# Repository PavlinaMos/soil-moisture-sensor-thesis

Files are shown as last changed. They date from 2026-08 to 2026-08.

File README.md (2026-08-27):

# Soil Moisture Sensor Thesis

This repository contains the soil-moisture measurement project:

- ESP32 firmware for impedance measurement, Wi-Fi provisioning, and Arduino Cloud publishing.
- KiCad schematic and PCB sources for the measurement hardware.
- R scripts used to analyze the soil samples examined in impedance spectroscopy 
- The editable LaTeX thesis and its figures.

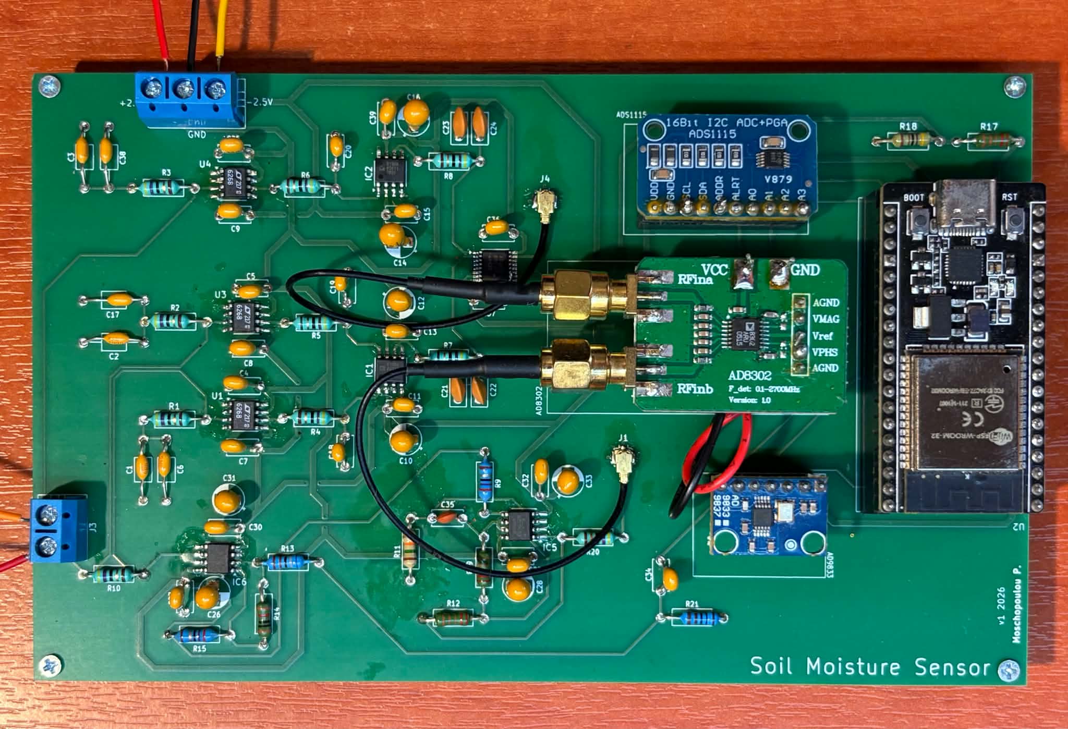
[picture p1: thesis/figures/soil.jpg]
Assembled soil moisture sensor


## Repository layout

```text
.
|-- firmware/                           ESP32 PlatformIO project
|   |-- include/                        Cloud definitions and local secrets
|   |-- src/                            Application code
|   `-- platformio.ini                  Board, framework, and library settings        
|-- analysis/impedance_spectroscopy/    R analysis scripts and usage notes
|-- PCB/kicad/soil-board/               KiCad schematic, PCB, and project files
|-- thesis/                             LaTeX sources, bibliography, and figures
```

## Firmware overview

The firmware targets an ESP32 NodeMCU-32S. It drives the measurement circuit,
calculates resistance (`RP`) and capacitance (`CP`), and publishes the results
to Arduino Cloud.

WiFiManager handles Wi-Fi setup without needing hard-coded network credentials. Known
networks are stored in the ESP32's non-volatile memory. At startup, the device
tries to connect to saved networks and opens a setup portal when none can
be reached.

### Analog parts

1. LTC6268
2. AD8130
3. AD8066
4. ADG733

### Modules

1. AD9833 waveform generator
2. ADS1115 ADC
3. AD8302 gain-phase detector

## Firmware development environment

Install:

1. [Visual Studio Code](https://code.visualstudio.com/)
2. The PlatformIO IDE extension for VS Code
3. The CP210x USB-to-UART driver if the ESP32 does not appear as a Windows COM port

Open the `firmware/` folder in VS Code. PlatformIO reads the exact toolchain and
library versions pinned in `firmware/platformio.ini`.

## Configure private secrets

Copy `firmware/include/arduino_secrets.h`, then add the matching Arduino Cloud
device key. Don't share its contents.

```cpp
#pragma once

#define SECRET_SSID ""
#define SECRET_PASS ""
#define SECRET_DEVICE_KEY "paste-your-Arduino-Cloud-device-key-here"
```

WiFiManager does not use `SECRET_SSID` or `SECRET_PASS` during normal
operation, they remain for compatibility. `SECRET_DEVICE_KEY` is required for
Arduino Cloud authentication.

## Build and upload the firmware

In VS Code, use the PlatformIO buttons in the bottom status bar:

- **Check mark**: build the project.
- **Right arrow**: upload the firmware to the ESP32.
- **Plug icon**: open the serial monitor.

The first build downloads and compiles dependencies, so it takes longer. 

To upload:

1. Connect the NodeMCU-32S using a USB data cable.
2. Confirm that Windows assigns it a COM port.
3. Click the PlatformIO **Upload** arrow.
4. If the board does not enter download mode automatically, hold **BOOT** until writing starts.

The serial monitor uses **115200 baud** and displays measurements, Wi-Fi state,
and Arduino Cloud connection messages.

## Wi-Fi provisioning

When no saved network can connect, the ESP32 creates the protected setup access
point `ESP32-Meter-Setup`. Connect with password `configure-me` and use the
captive portal (or `192.168.4.1`) to select a 2.4 GHz Wi-Fi network. The current
implementation stores up to five profiles; when the list is full, slot 0 is
replaced.

## Arduino Cloud

After joining Wi-Fi, the ESP32 connects to Arduino Cloud and publishes the
measurements periodically. The dashboard shows current `RP` and `CP` values and
their time history. Cloud retention depends on the Arduino Cloud plan.

## Hardware design

Open `PCB/kicad/soil-board/SoilBoard.kicad_pro` in KiCad. See the
[PCB notes](PCB/kicad/soil-board/README.md) for more info.

## Data analysis

The R scripts are under `analysis/impedance_spectroscopy/`. They cover
mean-squared error, Nyquist plots, sampled Nyquist comparisons, and
phase/impedance plots.

## Thesis

The thesis source is under `thesis/`. Its main document is `thesis/main.tex`
and it uses pdfLaTeX.

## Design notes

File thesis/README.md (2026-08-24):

#  Thesis - LaTeX project

This folder contains the current written progress of the thesis project.

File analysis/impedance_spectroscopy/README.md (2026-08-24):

# Impedance spectroscopy analysis

These scripts were used to process impedance measurements and create plots for
the thesis:

- `MeanSquaredError.R`: compares measured and modeled impedance and phase.
- `NyquistPlot.R`: plots Nyquist traces from CSV exports.
- `NyquistSamples.R`: compares selected trace groups 
- `PhaseVsFrequency.R`: plots impedance magnitude and phase against frequency.

The scripts are preserved as thesis analysis sources; they are not executed by
the ESP32 firmware build.

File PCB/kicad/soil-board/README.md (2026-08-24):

# SoilBoard KiCad project

Open `SoilBoard.kicad_pro` in KiCad to access the schematic and PCB layout.

## Included files

- `SoilBoard.kicad_pro`: KiCad project settings.
- `SoilBoard.kicad_sch`: schematic.
- `SoilBoard.kicad_pcb`: PCB layout.

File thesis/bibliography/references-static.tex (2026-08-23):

\begin{thebibliography}{99}
\addcontentsline{toc}{chapter}{ΒΙΒΛΙΟΓΡΑΦΙΑ}
\setlength{\itemsep}{0.45\baselineskip}\sloppy

\bibitem{ref01}
Soil Survey Staff, \emph{Soil Taxonomy: A Basic System of Soil
Classification for Making and Interpreting Soil Surveys}, 2nd ed., USDA
Handbook 436, Natural Resources Conservation Service, 1999.
\href{https://www.nrcs.usda.gov/resources/guides-and-instructions/soil-taxonomy}{Official
NRCS source}.

\bibitem{ref02}
Soil Science Division Staff, \emph{Soil Survey Manual}, C.
Ditzler, K. Scheffe, and H. C. Monger, eds., USDA Handbook 18, U.S.
Government Printing Office, 2017.
\href{https://www.nrcs.usda.gov/resources/guides-and-instructions/soil-survey-manual}{Official
NRCS source}.

\bibitem{ref03}
M. J. Escorihuela, P. de Rosnay, Y. H. Kerr, and J.-C. Calvet,
``Influence of Bound-Water Relaxation Frequency on Soil Moisture
Measurements,'' \emph{IEEE Transactions on Geoscience and Remote
Sensing}, vol. 45, no. 12, pp. 4067--4076, 2007.
\href{https://doi.org/10.1109/TGRS.2007.906090}{doi:10.1109/TGRS.2007.906090}.

\bibitem{ref04}
Keysight Technologies, \emph{Materials Testing: Electronic
Properties of Soil}, Application Note 5991-4717.

\bibitem{ref05}
METER Group, ``What Is Soil Moisture? The Science Behind the
Measurement.''
\href{https://metergroup.com/measurement-insights/what-is-soil-moisture-the-science-behind-the-measurement/}{Official
article}.

\bibitem{ref06}
Stevens Water Monitoring Systems, \emph{HydraProbe Soil Sensor
Documentation}.

\bibitem{ref07}
D. Neina, ``The Role of Soil pH in Plant Nutrition and Soil
Remediation,'' \emph{Applied and Environmental Soil Science}, vol. 2019,
Art. 5794869, 2019.
\href{https://doi.org/10.1155/2019/5794869}{doi:10.1155/2019/5794869}.

\bibitem{ref08}
University of Minnesota Extension, ``Soil Compaction.''
\href{https://extension.umn.edu/soil-management-and-health/soil-compaction}{Official
extension article}.

\bibitem{ref09}
J. D. Rhoades, F. Chanduvi, and S. M. Lesch, \emph{Soil Salinity
Assessment: Methods and Interpretation of Electrical Conductivity
Measurements}, FAO Irrigation and Drainage Paper 57, Food and
Agriculture Organization of the United Nations, 1999

\bibitem{ref10}
W. G. Fano, ``The Electrical Properties of Soils with Their
Applications to Agriculture, Geophysics, and Engineering,'' in
\emph{Electromagnetic Field Radiation in Matter}, IntechOpen, 2019.
\href{https://doi.org/10.5772/intechopen.88989}{doi:10.5772/intechopen.88989}.

\bibitem{ref11}
F. Wenner, ``A Method of Measuring Earth Resistivity,''
\emph{Bulletin of the Bureau of Standards}, vol. 12, pp. 469--478, 1916.
\href{https://nvlpubs.nist.gov/nistpubs/bulletin/12/nbsbulletinv12n4p469_A2b.pdf}{NIST
publication}.

\bibitem{ref12}
T. Barić, M. Pavić, and H. Glavaš, ``Modelling of the Wenner
Method Using the Finite Element Method,'' \emph{Engineering
Proceedings}, vol. 125, no. 1, Art. 10, 2026.
\href{https://doi.org/10.3390/engproc2026125010}{doi:10.3390/engproc2026125010}.

\bibitem{ref13}
J. D. Rhoades and R. D. Ingvalson, ``Determining Salinity in
Field Soils with Soil Resistance Measurements,'' \emph{Soil Science
Society of America Journal}, vol. 35, no. 1, pp. 54--60, 1971.
\href{https://doi.org/10.2136/sssaj1971.03615995003500010020x}{doi:10.2136/sssaj1971.03615995003500010020x}.

\bibitem{ref14}
N. Wiwattanachang, C. Vichalai, and P. H. Giao, ``Influence of
Calcium Carbonate Sludge on Cement-Stabilized Subgrade Quality as
Investigated by Means of Electrical Resistivity Measurements,''
\emph{Scientific Reports}, vol. 13, Art. 19392, 2023.
\href{https://doi.org/10.1038/s41598-023-46282-x}{doi:10.1038/s41598-023-46282-x}.

\bibitem{ref15}
S. Kaur, M. Sandhu, and J. Kaur, ``Dielectric Theory and Its
Properties,'' \emph{International Journal of Emerging Technologies in
Engineering Research (IJETER)}, vol. 4, no. 3, pp. 145--149, Mar. 2016.

\bibitem{ref16}
Electromagnetic Geophysics, ``Dielectric Permittivity.''
\href{https://em.geosci.xyz/content/physical_properties/dielectric_permittivity/index.html}{Official
reference page}.

\bibitem{ref17}
A. K. Bain and P. Chand, \emph{Pyroelectric Materials: Physics
and Applications}. Weinheim, Germany: Wiley-VCH, 2022

\bibitem{ref18}
Z. G. Datsios and P. N. Mikropoulos, "Characterization of the
frequency dependence of the electrical properties of sandy soil with
variable grain size and water content," in~\emph{IEEE Transactions on
Dielectrics and Electrical Insulation}, vol. 26, no. 3, pp. 904-912,
June 2019, doi: 10.1109/TDEI.2018.007864

\bibitem{ref19}
Stevens Water Monitoring Systems, \emph{HydraProbe Soil Sensor
Documentation}.

\bibitem{ref20}
S. Kaur, M. Sandhu, and J. Kaur, ``Dielectric Theory and Its
Properties,'' \emph{International Journal of Emerging Technologies in
Engineering Research (IJETER)}, vol. 4, no. 3, pp. 145--149, Mar. 2016.

\bibitem{ref21}
METER Group, ``Soil Moisture Sensors---How They Work and Why
Some Are Not Research Grade.''
\href{https://metergroup.com/measurement-insights/soil-moisture-sensors-how-they-work-why-some-are-not-research-grade/}{Official
article}.

\bibitem{ref22}
M. E. Orazem and B. Tribollet, \emph{Electrochemical Impedance
Spectroscopy}, 2nd ed., Wiley, 2017.
\href{https://doi.org/10.1002/9781119363682}{doi:10.1002/9781119363682}.

\bibitem{ref23}
W. Gustavo Fano, `The Electrical Properties of Soils with Their
Applications to Agriculture, Geophysics, and Engineering',
Electromagnetic Field Radiation in Matter. IntechOpen, Sep. 16, 2020.
doi: 10.5772/intechopen.88989.

\bibitem{ref24}
L. Umar and R. N. Setiadi, ``Low Cost Soil Sensor Based on
Impedance Spectroscopy for In-Situ Measurement,'' \emph{AIP Conference
Proceedings}, vol. 1656, Art. no. 040005, 2015, doi: 10.1063/1.4917112.

\bibitem{ref25}
Z. -y. Chang, B. P. Iliev and G. C. M. Meijer, "A Sensor
Interface System for Measuring the Impedance (Cx, Rx) of Soil at a
Signal Frequency of 20MHz,"~\emph{SENSORS, 2007 IEEE}, Atlanta, GA, USA,
2007, pp. 268-271, doi: 10.1109/ICSENS.2007.4388388.

\bibitem{ref26}
Z. -y. Chang, B. P. Iliev, J. F. de Groot and G. C. M. Meijer,
"Extending the Limits of a Capacitive Soil-Water-Content Measurement,"
in~\emph{IEEE Transactions on Instrumentation and Measurement}, vol. 56,
no. 6, pp. 2240-2244, Dec. 2007, doi: 10.1109/TIM.2007.908317.

\bibitem{ref27}
Rêgo Segundo, A.K.; Martins, J.H.; Monteiro, P.M.d.B.; De
Oliveira, R.A.; Freitas, G.M. A Novel Low-Cost Instrumentation System
for Measuring the Water Content and Apparent Electrical Conductivity of
Soils.~\emph{Sensors}~\textbf{2015},~\emph{15}, 25546-25563.
\url{https://doi.org/10.3390/s151025546}

\bibitem{ref28}
Α. Ιωάννου, Γ. Ντάνος, Α. Πήττας και Σ. Ράπτης, \emph{Φυσική:
Τεύχος Β΄, Ομάδας Προσανατολισμού Θετικών Σπουδών \& Σπουδών Υγείας, Γ΄
τάξη Γενικού Λυκείου}. Αθήνα, Ελλάδα: Ινστιτούτο Τεχνολογίας Υπολογιστών
και Εκδόσεων (ΙΤΥΕ) «Διόφαντος», 2019

\bibitem{ref29}
-

\bibitem{ref30}
C. Chassagne, E. Dubois, M. L. Jiménez, J. P. M. van der Ploeg,
and J. van Turnhout, ``Compensating for Electrode Polarization in
Dielectric Spectroscopy Studies of Colloidal Suspensions: Theoretical
Assessment of Existing Methods,'' \emph{Frontiers in Chemistry}, vol. 4,
Art. 30, 2016.
\href{https://doi.org/10.3389/fchem.2016.00030}{doi:10.3389/fchem.2016.00030}.

\bibitem{ref31}
Keysight Technologies, \emph{E4990A Impedance Analyzer Data
Sheet}, publication 5991-3890.
\href{https://www.keysight.com/zz/en/assets/7018-04256/data-sheets/5991-3890.pdf}{Official
data sheet}.

\bibitem{ref32}
Analog Devices, \emph{AD9833: Low Power, Programmable Waveform
Generator}.
\href{https://www.analog.com/en/products/ad9833.html}{Official product
page and data sheet}.

\bibitem{ref33}
Analog Devices, \emph{AD8302: RF/IF Gain and Phase Detector}.
\href{https://www.analog.com/en/products/ad8302.html}{Official product
page and data sheet}.

\bibitem{ref34}
Texas Instruments, \emph{ADS1115: 16-Bit, 860-SPS, Four-Channel
Delta-Sigma ADC with PGA, Oscillator, Voltage Reference, Comparator, and
I2C}. \href{https://www.ti.com/product/ADS1115}{Official product page
and data sheet}.

\bibitem{ref35}
Analog Devices, \emph{AD8065/AD8066: High Performance, 145 MHz
FastFET Operational Amplifiers}.
\href{https://www.analog.com/en/products/ad8066.html}{Official product
page and data sheet}.

\bibitem{ref36}
Analog Devices, \emph{LTC6268/LTC6269: 500 MHz Ultra-Low Bias
Current FET Input Op Amps}.
\href{https://www.analog.com/en/products/ltc6268.html}{Official product
page and data sheet}.

\bibitem{ref37}
Analog Devices, \emph{ADG733: CMOS, Low Voltage, 2.5 Ohm Triple
SPDT Switch}.
\href{https://www.analog.com/en/products/adg733.html}{Official product
page and data sheet}.

\bibitem{ref38}
Analog Devices, \emph{AD8129/AD8130: Low Cost 270 MHz
Differential Receiver Amplifiers}.
\href{https://www.analog.com/en/products/ad8130.html}{Official product
page and data sheet}.

\bibitem{ref39}
Espressif Systems, \emph{ESP32 Series Data Sheet}.
\href{https://www.espressif.com/sites/default/files/documentation/esp32_datasheet_en.pdf}{Official
data sheet}.

\end{thebibliography}

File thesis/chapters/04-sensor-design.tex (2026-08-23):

\chapter{Σχεδιασμός και Υλοποίηση Αισθητήρα}
\label{ch:sensor}

\section{Εισαγωγή}

Στο συγκεκριμένο κεφάλαιο θα εξεταστεί αναλυτικά η αρχιτεκτονική και οι
αρχές λειτουργίας του συστήματος. Παρουσιάζονται τα δομικά στοιχεία με
τα χαρακτηριστικά τους, η θεωρία λειτουργίας του αισθητήρα, το
σχηματικό, οι απαιτήσεις και οι περιορισμοί του συστήματος καθώς και η
τελική πλακέτα.

\section{Δομικά Στοιχεία του Συστήματος}

\subsection{Γεννήτρια DDS}

Ο υπολογισμός της σύνθετης αντίστασης του δείγματος απαιτεί τη διέγερση
του από ένα ηλεκτρικό σήμα μέσω των ηλεκτροδίων και μίας αντίστασης
(shunt resistor) συνδεδεμένη σε σειρά. Για τη δημιουργία του σήματος
επιλέχθηκε ο DDS (Direct Digital Synthesis) AD9833. Πρόκειται για ένα
ολοκληρωμένο κύκλωμα που επιτρέπει την παραγωγή ημιτοειδών, τετραγωνικών
και τριγωνικών κυματομορφών. Επιλέχθηκε λόγω του χαμηλού κόστους και
κατανάλωσης ισχύος, αλλά και τον εύκολο έλεγχο μέσω SPI για τον
προγραμματισμό του επιθυμητού σήματος και συχνότητας μέσω του
μικροελεγκτή. Υποστηρίζει συχνότητες εξόδου από 0-12.5 MHz και παρέχει
πλάτος εξόδου περίπου 0,6Vpp. \cite{ref32}

\begin{figure}[H]
  \centering
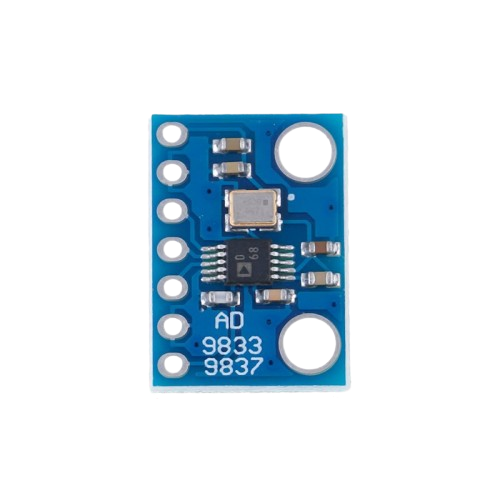
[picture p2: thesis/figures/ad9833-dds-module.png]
  
  \caption{Μονάδα γεννήτριας DDS AD9833.}
  \label{fig:ad9833-module}
\end{figure}

\subsection{Ανιχνευτής Κέρδους-Φάσης}

Για τον υπολογισμό της πτώσης τάσης και της διαφοράς φάσης μεταξύ τάσης
και ρεύματος του δείγματος χρησιμοποιήθηκε η μονάδα \textbf{AD8302}.
Πρόκειται για ένα ολοκηρωμένο κύκλωμα ανίχνευσης κέρδους και φάσης
μεταξύ δύο AC σημάτων εισόδου, το οποίο παράγει στην έξοδο δύο DC τιμές
τάσεων, μία για το λόγο των πλατών και μία για τη διαφορά φάσης
αντίστοιχα. Η ευαισθησία της εξόδου είναι 30mV/db για το κέρδος και
10mV/° για τη φάση, ενώ μπορεί να δεχθεί σήματα συχνότητας έως και
2.7GHz. Παρακάτω φαίνεται το εξιδανικευμένο διάγραμμα εισόδων-εξόδου για
την εκάστοτε έξοδο. \cite{ref33}

\begin{figure}[H]
  \centering
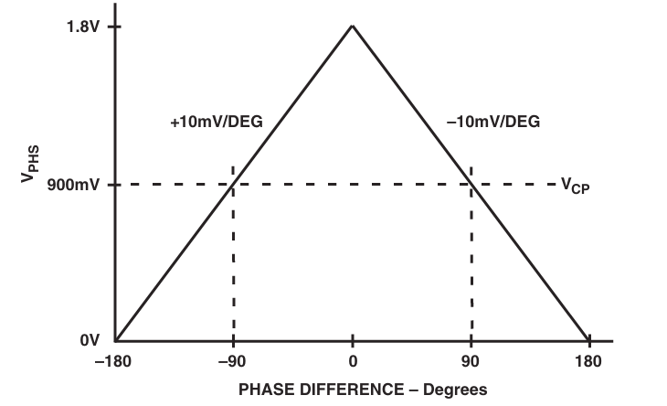
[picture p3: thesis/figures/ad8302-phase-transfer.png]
  
  \caption{Ιδανική χαρακτηριστική εξόδου φάσης του AD8302.}
  \label{fig:ad8302-phase-transfer}
\end{figure}

\begin{figure}[H]
  \centering
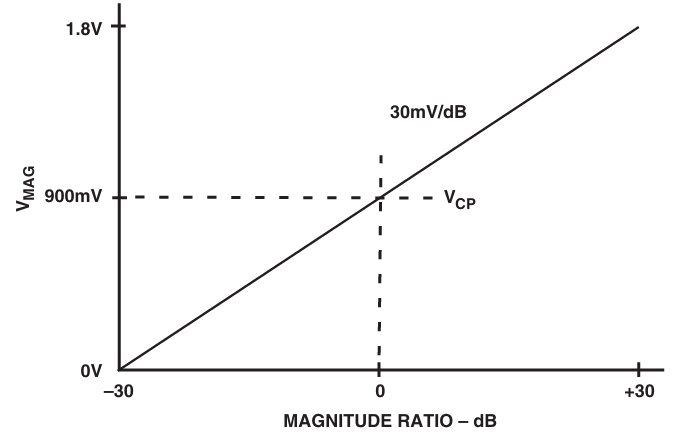
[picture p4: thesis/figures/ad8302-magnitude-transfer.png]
  
  \caption{Ιδανική χαρακτηριστική εξόδου λόγου πλατών του AD8302.}
  \label{fig:ad8302-magnitude-transfer}
\end{figure}

Η συνάρτηση μεταφοράς της εξόδου για το λόγο των πλατών δίνεται από τη
σχέση

\[V_{MAG} = 0,9 + 0,03 \cdot \left( 20\log\frac{\left| V_{a} \right|}{\left| V_{b} \right|} \right)\]

ενώ για τη φάση ισχύει

\[V_{PHASE} = 0,9 - 0,01 \cdot \left( \Delta\varphi - 90^{\circ} \right)\]

\subsection{Μονάδα Analog-to-Digital Converter}

Για τη δειγματοληψία των τιμών εξόδου του ανιχνευτή κέρδους-φάσης
χρησιμοποιήθηκε o εξωτερικός μετατροπέας αναλογικών σε ψηφιακό σήμα
(ADC) \textbf{ADS1115} των 16bits για καλύτερη ακρίβεια. Διαθέτει
τέσσερα κανάλια εισόδου κι επικοινωνεί με το πρωτόκολλο
I\textsuperscript{2}C. \cite{ref34}

\begin{figure}[H]
  \centering
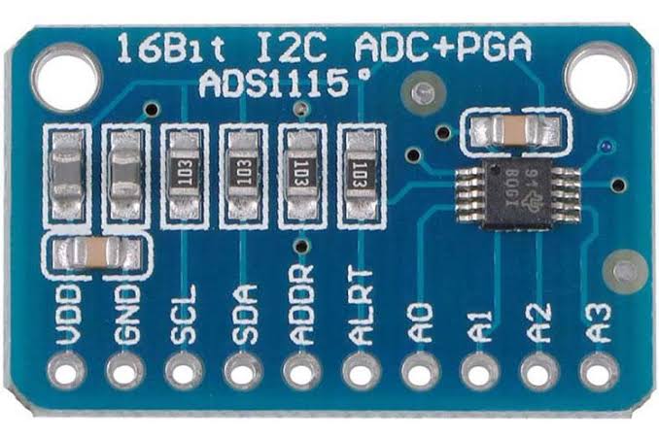
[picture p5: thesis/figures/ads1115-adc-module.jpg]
  
  \caption{Μονάδα μετατροπέα αναλογικού σε ψηφιακό σήμα ADS1115 των 16bits.}
  \label{fig:ads1115-module}
\end{figure}

\subsection{Ολοκληρωμένα Κυκλώματα}

Για τη διαμόρφωση των αναλογικών σημάτων (signal conditioning)
επιλέχθηκε ο \textbf{AD8066} λόγω της χαμηλής του κατανάλωσης. Για την
απομόνωση των σημάτων του κυκλώματος χρησιμοποιήθηκε ο \textbf{LTC6268}
σε συνδεσμολογία ακόλουθου τάσης (voltage follower). Η επιλογή του
βασίστηκε στην εξαιρετικά χαμηλή χωρητικότητα εισόδου της τάξης των fF
και στο πολύ χαμηλό ρεύμα πόλωσης (input bias current) στην κλίμακα των
pA, προκειμένου να ελαχιστοποιηθεί η φόρτωση του δείγματος και να
αποφευχθεί η αλλοίωση των πραγματικών ηλεκτρικών χαρακτηριστικών. \cite{ref35,ref36}

Στη συνέχεια, τα παραπάνω σήματα οδηγούνται μέσω του αναλογικού διακόπτη
\textbf{ADG733} στους διαφορικούς ενισχυτές \textbf{AD8130.} Πρόκειται
για έναν high-speed διαφορικό ενισχυτή που δεν απαιτεί εξωτερικά
εξαρτήματα και προσφέρει υψηλή απόρριψη κοινού θορύβου, με περίπου -80db
στο 1MHz. \cite{ref37,ref38}

\subsection{Μικροελεγτκής}

Για τον έλεγχο και το συντονισμό της λειτουργίας του συστήματος
χρησιμοποιήθηκε ο μικροελεγκτής ESP32-NodeMCU-32s. Ο μικροελεγκτής
αναλαμβάνει το ρόλο του προγραμματισμού της γεννήτριας AD9833 μέσω του
πρωτοκόλλου SPI, τη λήψη των δεδομένων από τον μετατροπέα ADS1115 με το
πρωτόκολλο \(I^{2}C\), τον έλεγχο του αναλογικού διακόπτη και τέλος την
εκτέλεση των απαραίτητων πράξεων για τον υπολογισμό της σύνθετης
αντίστασης και την εκτίμηση της υγρασίας του δείγματος. \cite{ref39}

\section{Απαιτήσεις του Συστήματος}

Μία από τις απαιτήσεις του συστήματος είναι η ανίχνευση μικρών μεταβολών
της χωρητικότητας. Σύμφωνα με τις μετρήσεις που πραγματοποιήθηκαν με τον
Αναλυτή Εμπέδησης, η διακύμανση της χωρητικότητας στα δείγματα που
εξετάστηκαν ήταν της τάξης των δεκάδων pF. Τόσο χαμηλές χωρητικότητες
μπορούν εύκολα να επισκιαστούν από παρασιτικές χωρητικότητες,
παρεμβολές, ακατάλληλο σχεδιασμό της πλακέτας και γενικότερα συστημικά
σφάλματα. Έτσι, δόθηκε ιδιαίτερη προσοχή στο σχεδιασμό προκειμένου να
ελαχιστοποιηθούν τα σφάλματα στο μέγιστο δυνατό.

Ακόμη, ένα μειονέκτημα του ανιχνευτή κέρδους-φάσης είναι η μη
γραμμικότητα των συναρτήσεων εξόδου για διαφορά φάσης από
0\textsuperscript{ο} έως +-30\textsuperscript{ο} (\figref{fig:ad8302-phase-error}). Από τον
αναλυτή εμπέδησης φάνηκε πως η φάση των δειγμάτων κυμαινόταν από τιμές
κοντά στις 0\textsuperscript{ο} έως και τις -10\textsuperscript{ο}. Για
αυτό το λόγο, δημιουργήθηκε ένα τρίτο σήμα αναφοράς Vereference με
αρκετά μεγαλύτερη διαφορά φάσης συγκριτικά με τα δύο σήματα που
λαμβάνονται από το σύστημα, προκειμένου να μειωθεί το σφάλμα εξόδου.
Εφόσον ληφθεί η μέτρηση του κάθε σήματος αναφορικά με το Vreference,
γίνεται μαθηματικά η απαλοιφή του Vreference μέσω του μικροελεγκτή και
εξάγεται το τελικό V\textsubscript{MAG} και V\textsubscript{PHASE} των
δύο σημάτων ενδιαφέροντος.

\begin{figure}[H]
  \centering
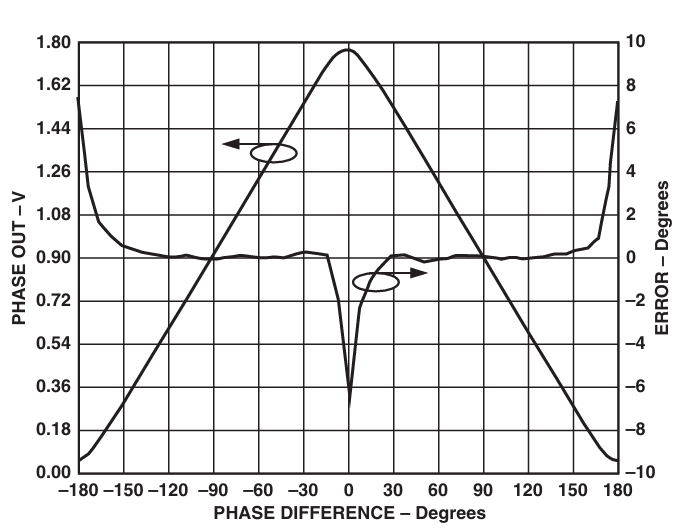
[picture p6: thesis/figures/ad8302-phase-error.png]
  
  \caption{Χαρακτηριστική εξόδου φάσης και σφάλματος του AD8302 συναρτήσει της διαφοράς φάσης. \cite{ref33}}
  \label{fig:ad8302-phase-error}
\end{figure}

\section{Προσέγγιση και Μεθοδολογία}

Στο \figref{fig:sensor-architecture} φαίνεται η συνολική αρχιτεκτονική του συστήματος. Αρχικά,
ο DDS παράγει ένα ημιτονοειδές σήμα συχνότητας 1MHz και πλάτους 0,6mVpp,
το οποίο περιλαμβάνει μία DC συνιστώσα (DC offset). Ωστόσο, επειδή μία
DC συνιστώσα θα προκαλούσε οξείδωση στα ηλεκτρόδια λόγω της
ηλεκτρόλυσης, το σήμα θα πρέπει να είναι καθαρά εναλλασσόμενο (AC). Για
αυτό το λόγο, στην έξοδο του DDS έχει τοποθετηθεί ένα υψηπερατό φίλτρο
όπως φαίνεται στο \figref{fig:sensor-architecture} με συχνότητα αποκοπής

\[f = \frac{1}{2\pi * R_{21} * C_{34}} = \frac{1}{2\pi * 1k * 0.1u} = 1.6kHz\]

\begin{figure}[H]
  \centering
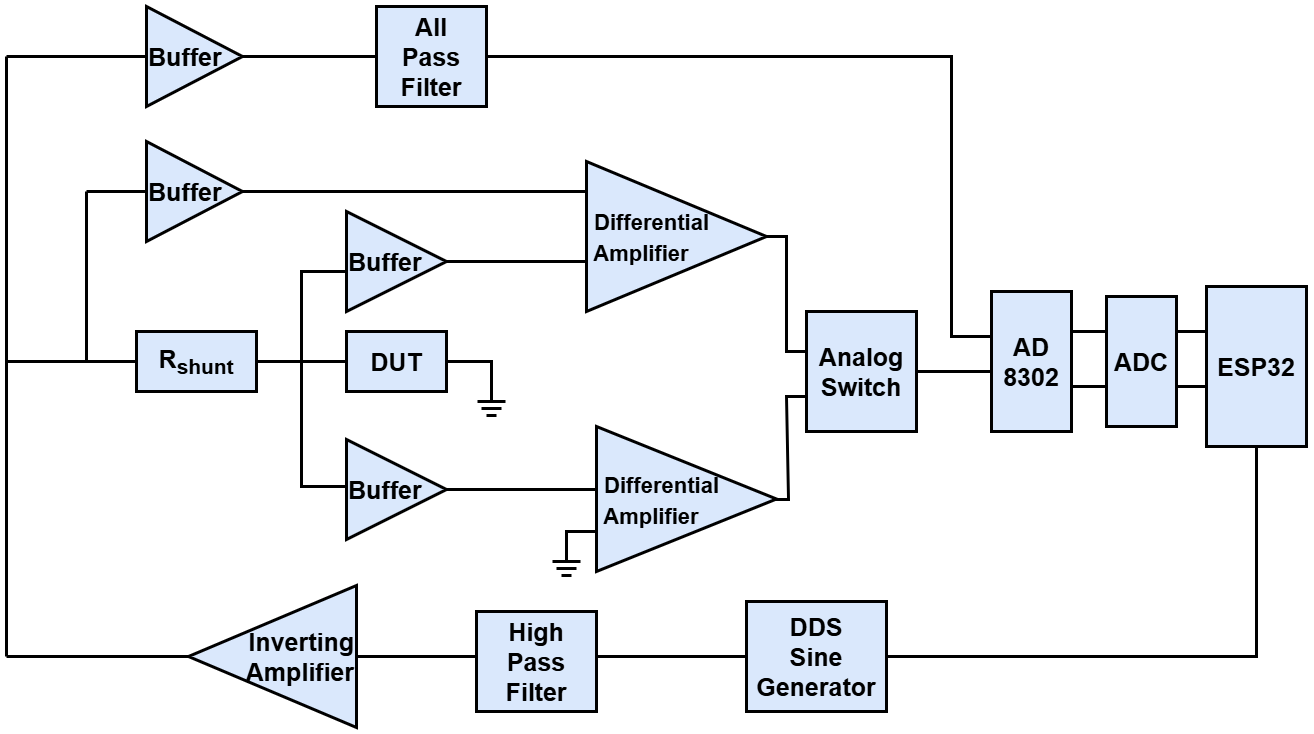
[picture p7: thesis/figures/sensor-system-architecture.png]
  
  \caption{Συνολική αρχιτεκτονική του συστήματος.}
  \label{fig:sensor-architecture}
\end{figure}

\begin{figure}[H]
  \centering
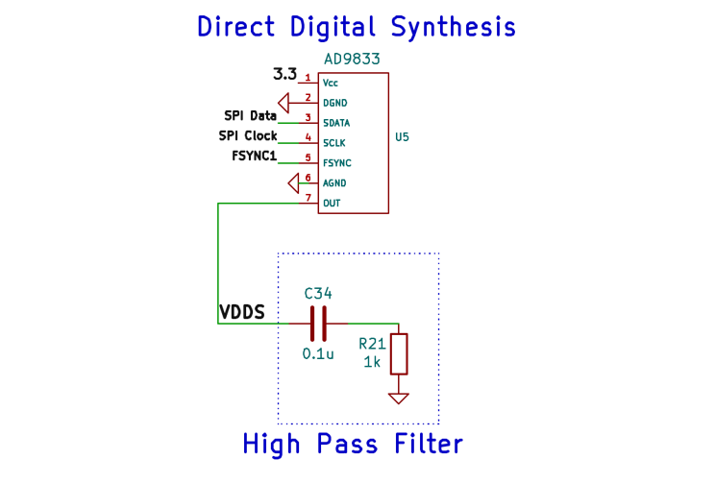
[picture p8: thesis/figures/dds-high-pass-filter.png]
  
  \caption{Η μονάδα παραγωγής σημάτων και το υψηπερατό φίλτρο}
  \label{fig:dds-high-pass-filter}
\end{figure}

Στη συνέχεια, για τη βελτίωση του SNR το σήμα ενισχύεται μέσω ενός
τελεστικού σε συνδεσμολογία αναστρέφοντα ενισχυτή με κέρδος

\[A_{v} = - \ \frac{R_{14}}{R_{13}} = \  - \ \frac{10k}{6.8k} = - 1.5\]

Το σήμα αυτό χρησιμοποιείται για τη διέγερση του δείγματος αλλά και την
παραγωγή του σήματος αναφοράς, οπότε και στέλνεται μέσω του All Pass
φίλτρου για τη δημιουργία καθυστέρησης φάσης περίπου \(35^{\circ}\) σε σχέση
με το αρχικό σήμα (\figref{fig:excitation-reference-conditioning}).

\begin{figure}[H]
  \centering
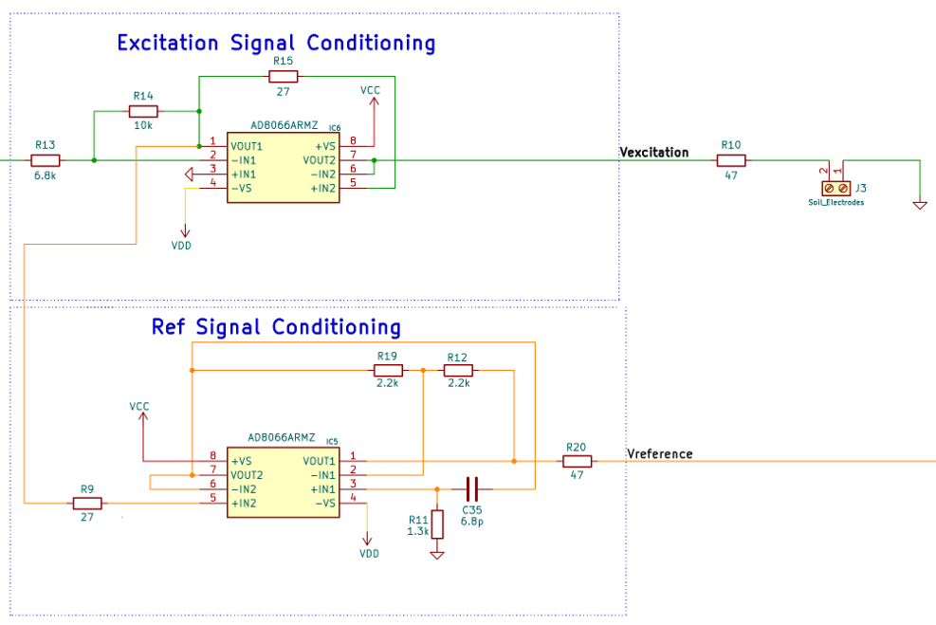
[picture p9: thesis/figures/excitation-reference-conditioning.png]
  
  \caption{Η διαμόρφωση των σημάτων διέγερσης και αναφοράς. Ο άνω τελεστικός λειτουργεί ως αναστρέφων ενισχυτής ενώ ο κάτω τελεστικός σε συνδεσμολογία All Pass Filter εισάγει τη διαφορά φάσης.}
  \label{fig:excitation-reference-conditioning}
\end{figure}

Κατά την εφαρμογή του σήματος διέγερσης στο δείγμα και την αντίσταση
αναφοράς (R10), τα σήματα στα άκρα των δύο στοιχείων λαμβάνονται μέσω
κυκλωμάτων απομόνωσης (buffers) τα οποία διαθέτουν πολύ υψηλή αντίσταση
αλλά χαμηλή χωρητικότητα εισόδου (\figref{fig:signal-buffering-filtering}). Στη συνέχεια, οδηγούνται
στους διαφορικούς ενισχυτές για τον υπολογισμό της πτώσης τάσεων στα δύο
στοιχεία (\figref{fig:differential-amplifiers-switching}).

\begin{figure}[H]
  \centering
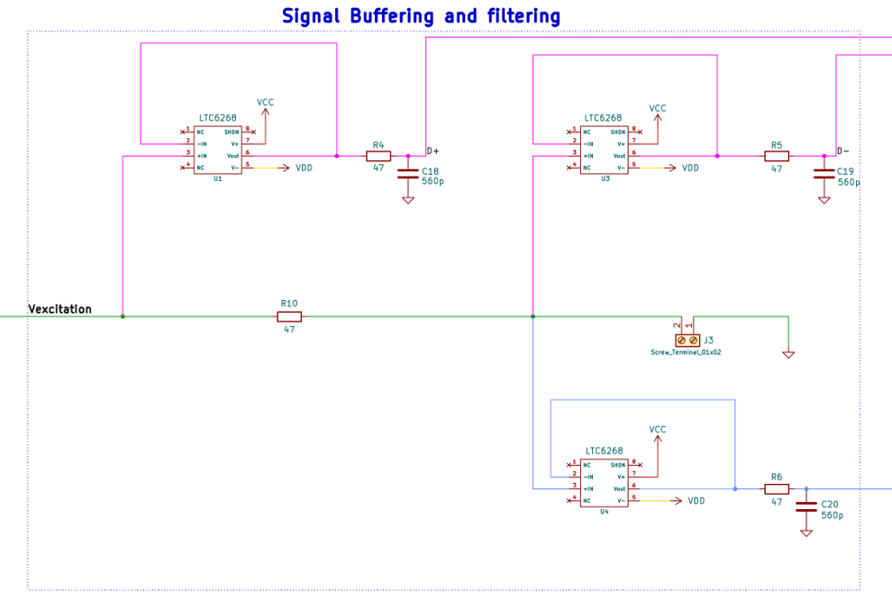
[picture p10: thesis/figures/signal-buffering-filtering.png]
  
  \caption{Οι τελεστικοί στα άκρα της αντίστασης και του δείγματος σε συνδεσμολογία ακολούθου τάσης και τα χαμηλοπερατά φίλτρα στις εξόδους τους.}
  \label{fig:signal-buffering-filtering}
\end{figure}

Τα δύο σήματα εξόδου των διαφορικών ενισχυτών, οδηγούνται σε έναν
αναλογικό διακόπτη, ο οποίος ελέγχεται από μία έξοδο (GPIO) του ESP32.
Τελικά, στην είσοδο του ανιχνευτή κέρδους φάσης καταλήγει το σήμα
αναφοράς και, εναλλάξ, τα δύο σήματα που επιλέγονται από τον
διακόπτη προκειμένου να πραγματοποιηθεί η μέτρηση για το κάθε στοιχείο
ξεχωριστά (\figref{fig:differential-amplifiers-switching}). Η έξοδος του ανιχνευτή δειγματοληπτείται από τον
εξωτερικό μετατροπέα αναλογικού σε ψηφιακό ώστε να γίνουν οι απαραίτητοι
υπολογισμοί μέσω του μικροελεγκτή για την εξαγωγή των ηλεκτρικών
παραμέτρων του δείγματος (\figref{fig:phase-gain-detector-adc})

\begin{figure}[H]
  \centering
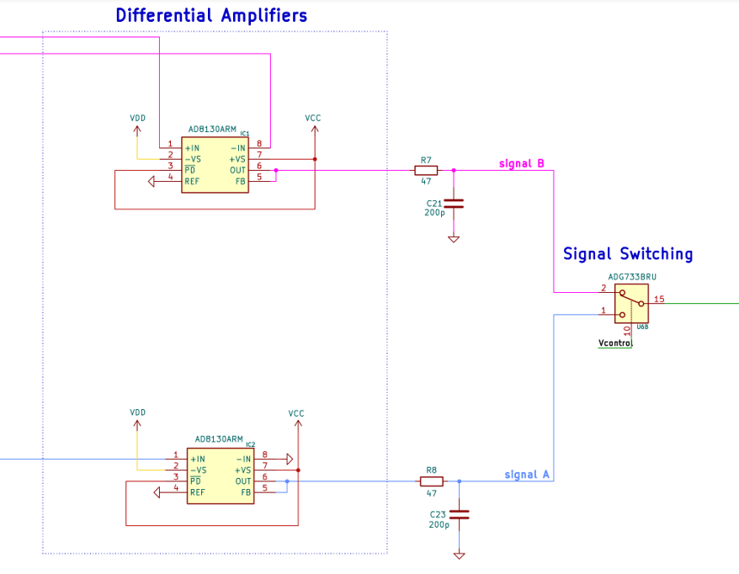
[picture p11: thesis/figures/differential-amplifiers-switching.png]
  
  \caption{Τα σήματα οδηγούνται στους  διαφορικικούς ενισχυτές όπου μέσω δύο χαμηλοπερατών φίλτρων παιρνούν στον αναλογικό διακόπτη.}
  \label{fig:differential-amplifiers-switching}
\end{figure}

\begin{figure}[H]
  \centering
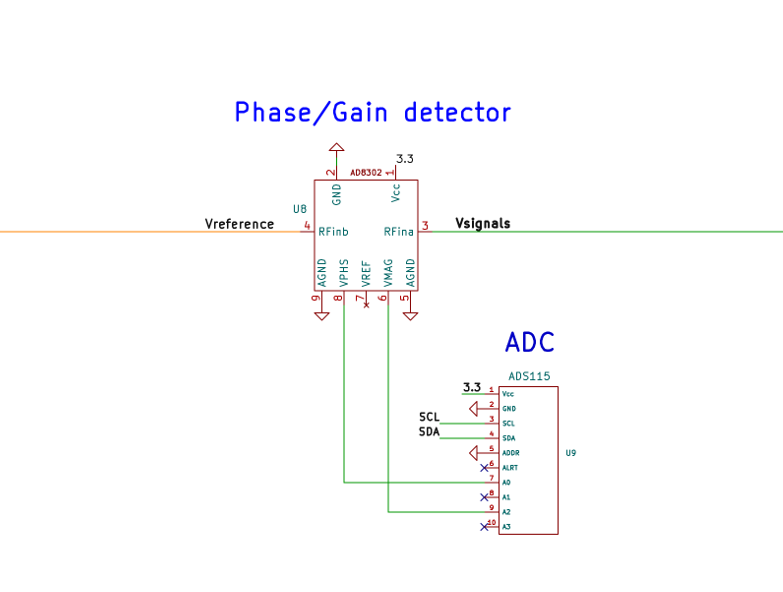
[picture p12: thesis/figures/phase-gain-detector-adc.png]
  
  \caption{Τα σήματα οδηγούνται στον ανιχνευτή κέρδους-τάσης και στη συνέχεια οι έξοδοι του διαβάζονται από τον ADC.}
  \label{fig:phase-gain-detector-adc}
\end{figure}

Έστω ότι ορίζουμε ως \(V_{A}\) τη διαφορά τάσης στα άκρα των
ηλεκτροδίων, \(V_{B}\) τη διαφορά τάσης στα άκρα της αντίστασης και
\(V_{ref}\) το διαμορφωμένο σήμα με καθυστέρηση φάσης \(35^{\circ}\). Ως \(\left|\Delta\varphi_{1}\right|\) ορίζεται το μέτρο της διαφοράς φάσης μεταξύ  \(V_{A}\) και του σήματος αναφοράς \(V_{ref}\) . Αντίστοιχα, ως \(\left|\Delta\varphi_{2}\right|\) ορίζεται το μέτρο της διαφοράς φάσης μεταξύ  \(V_{B}\) και του \(V_{ref}\) . Μετά
από δύο εναλλαγές του διακόπτη, μετρώνται τα παρακάτω ζεύγη μεγεθών

\[
V_{\mathrm{MAG}1}=0{,}9+0{,}03\left(20\log_{10}
\frac{\left|V_{A}\right|}{\left|V_{ref}\right|}\right)
\tag{10}
\]

\[
V_{\mathrm{PHASE}1}
=
0{,}9
-
0{,}01
\left(
\left|\Delta\varphi_{1}\right|
-
90^{\circ}
\right)
\tag{11}
\]

και

\[
V_{\mathrm{MAG}2}=0{,}9+0{,}03\left(20\log_{10}
\frac{\left|V_{B}\right|}{\left|V_{ref}\right|}\right)
\tag{12}
\]

\[
V_{\mathrm{PHASE}2}
=
0,9
-
0,01
\left(
\left|\Delta\varphi_{2}\right|
-
90^{\circ}
\right)
\tag{13}
\]

Για τη σχέση (10), ισχύει

\[
\log_{10}\left(\frac{\left|V_{A}\right|}{\left|V_{ref}\right|}\right)
=\frac{V_{\mathrm{MAG}1}-0{,}9}{0{,}6}
\]

και επομένως

\[
\left|V_{A}\right|=
10^{\frac{V_{\mathrm{MAG}1}-0{,}9}{0{,}6}}\left|V_{ref}\right|
\tag{14}
\]

Ενώ αντίστοιχα για το \(V_{B}\) ισχύει

\[
\left|V_{B}\right|=
10^{\frac{V_{\mathrm{MAG}2}-0{,}9}{0{,}6}}\left|V_{ref}\right|
\tag{15}
\]

Για να βρεθεί ο λόγος των πλατών, διαιρούνται κατά μέλη οι σχέσεις (14)
και (15) και προκύπτει τελικά

\[
\frac{\left|V_{A}\right|}{\left|V_{B}\right|}
=10^{\frac{V_{\mathrm{MAG}1}-V_{\mathrm{MAG}2}}{0{,}6}}
\tag{16}
\]

Από τις σχέσεις (11) και (13) υπολογίζονται αντίστοιχα οι διαφορές φάσης

\[
\left|\Delta\varphi_{1}\right|
=\frac{0{,}9-V_{\mathrm{PHASE}1}}{0{,}01}+90^{\circ}
\tag{17}
\]

και

\[
\left|\Delta\varphi_{2}\right|
=\frac{0{,}9-V_{\mathrm{PHASE}2}}{0{,}01}+90^{\circ}.
\tag{18}
\]

Η διαφορά φάσης των δύο σημάτων ενδιαφέροντος προκύπτει με απαλοιφή της
κοινής φάσης του σήματος αναφοράς. Θεωρώντας ότι το σήμα αναφοράς προηγείται κατά $35^\circ$ περίπου μοίρες από τα άλλα δύο, έχουμε $\varphi_1-\varphi_3>0$ και $\varphi_2-\varphi_3>0$ όπου $\varphi_3$ το σήμα αναφοράς, επομένως ισχύει

\[
\Delta\varphi
= |\Delta\varphi_1|-|\Delta\varphi_2|
= |\varphi_1-\varphi_3|-|\varphi_2-\varphi_3|
= \Delta\varphi_1-\Delta\varphi_2
= \frac{V_{\mathrm{PHASE}2}-V_{\mathrm{PHASE}1}}{0{,}01}.
\tag{19}
\]

Θεωρώντας \(R\) την αντίσταση αναφοράς \(R_{10}\), το ίδιο ρεύμα διαρρέει
την αντίσταση και το δείγμα. Επομένως, η σύνθετη αντίσταση του δείγματος
υπολογίζεται ως

\[
\begin{aligned}
\vec{Z}
&=\frac{\vec{V}_{A}}{\vec{I}}
 =\frac{\vec{V}_{A}}{\vec{V}_{B}/R}
 =R\frac{\vec{V}_{A}}{\vec{V}_{B}} \\
&=R\frac{\left|V_{A}\right|}{\left|V_{B}\right|}
  \angle\left(\Delta\varphi_{1}-\Delta\varphi_{2}\right) \\
&=R\,10^{\frac{V_{\mathrm{MAG}1}-V_{\mathrm{MAG}2}}{0{,}6}}
  \angle\left(\frac{V_{\mathrm{PHASE}2}-V_{\mathrm{PHASE}1}}{0{,}01}\right).
\end{aligned}
\tag{20}
\]

Για την εξαγωγή των παραμέτρων του παράλληλου ισοδύναμου
\(R_{p}\)-\(C_{p}\), χρησιμοποιείται η αγωγιμότητα

\[
\begin{aligned}
\vec{Y}
&=\frac{1}{\vec{Z}}
 =\frac{1}{\left|Z\right|e^{j\varphi}} \\
&=\frac{1}{\left|Z\right|}
  \left(\cos\varphi-j\sin\varphi\right).
\end{aligned}
\tag{21}
\]

Από το Κεφάλαιο 3 θεωρώντας ως ηλεκτρικό ισοδύναμο το παράλληλο Rp-Cp, ισχύει επίσης

\[
\vec{Y}=\frac{1}{R_{p}}+j\omega C_{p}=G+jB,
\tag{22}
\]

όπου \(\omega=2\pi f\). Εξισώνοντας το πραγματικό και το φανταστικό μέρος
των σχέσεων (21) και (22), προκύπτουν

\[
G=\frac{1}{R_{p}}=\frac{\cos\varphi}{\left|Z\right|},
\qquad
B=\omega C_{p}=-\frac{\sin\varphi}{\left|Z\right|}.
\tag{23}
\]

Τελικά, οι παράμετροι του ισοδύναμου κυκλώματος δίνονται από τις σχέσεις

\[
R_{p}=\frac{\left|Z\right|}{\cos\varphi},
\qquad
C_{p}=-\frac{\sin\varphi}{\omega\left|Z\right|}.
\tag{24}
\]

\section{Τυπωμένο Κύκλωμα}

Η πλακέτα σχεδιάστηκε με τη χρήση του λογισμικού Kicad. Είναι διπλής όψεος κι έχει διαστάσεις περίπου 10cm x 17cm (Σχήμα 4.12). Τα σήματα διατηρήθηκαν όσο ήταν εφικτό στο άνω επίπεδο, προκειμένου το κάτω επίπεδο που ορίστηκε ως η γείωση να παραμείνει όσο το δυνατό συνεχές. Τα αναλογικά σήματα συγκεντρώθηκαν στην αριστερή μερία της πλακέτας, ενώ τα ψηφιακά τοποθετήθηκαν στα δεξιά για να αποφευχθούν ανεπιθύμητες συζεύξεις (crosstalk). Τα σήματα που οδηγούνται στο διαφορικό ενισχυτή σχεδιάστηκαν ως  διαφορικό ζεύγος (differential pair), με στόχο τη μείωση του κοινού θορύβου. Η μονάδα AD8302 διαθέτει εισόδους SMA, επομένως για τη μεταφορά των σημάτων από την πλακέτα στη μονάδα ανίχνευσης κέρδους-φάσης χρησιμοποιήθηκαν U.FL connectors και καλώδια U.FL-SMA.

\begin{figure}[H]
  \centering
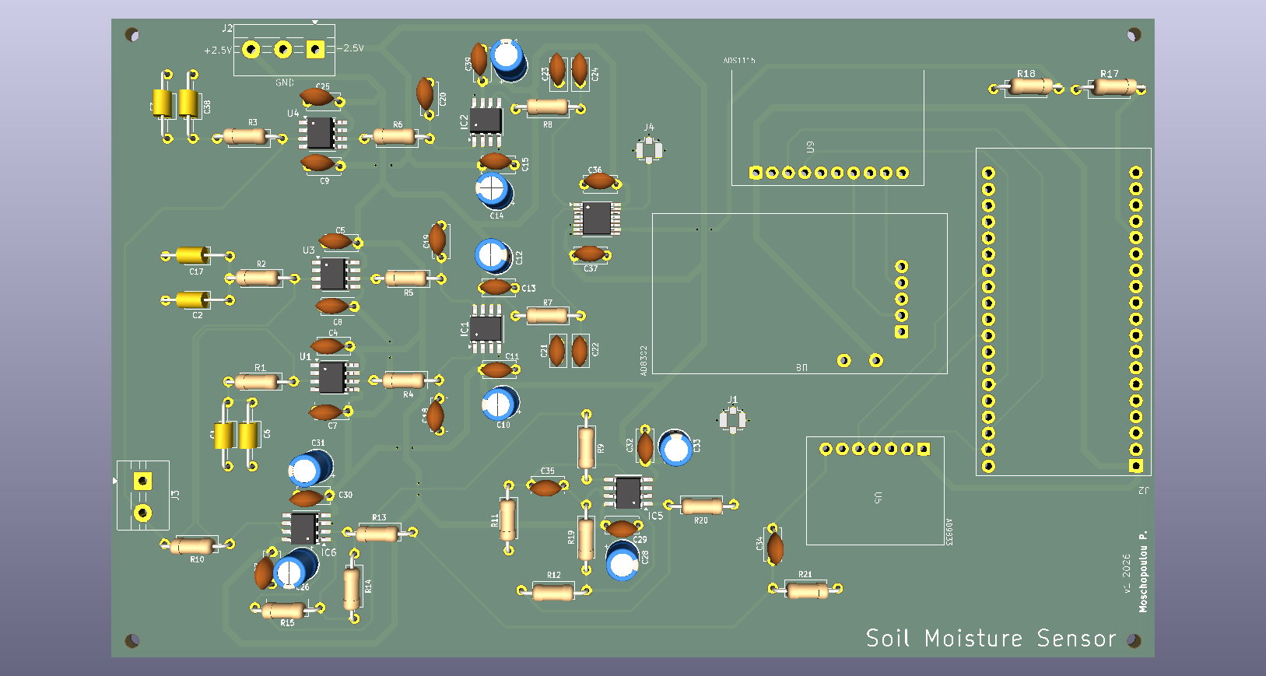
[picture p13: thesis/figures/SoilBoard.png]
  
  \caption{Το προσχέδιο της πλακέτας από το λογισμικό σχεδίασης. }
  \label{fig:signal-buffering-filtering}
\end{figure}

Τα ολοκληρωμένα κυκλώματα είναι τύπου SMD, ενώ τα υπόλοιπα στοιχεία είναι through hole.
Οι γραμμές τροφοδοσίας των ολοκληρωμένων κυκλωμάτων είναι στα +2.5V και -2.5V ενώ ο ESP32 τροφοδοτείται με 3.3V. Στις τροφοδοσίες των ολοκληρωμένων τοποθετήθηκαν κεραμικοί πυκνωτές αποσύζευξης (decoupling capacitors) με τιμές 0.1uF και 10uF όσο το δυνατόν κοντά στους ακροδέκτες. Οι πυκνωτές αυτοί συμβάλλουν στη διασφάλιση σταθερής τροφοδοσίας, καθώς οι πυκνωτές των 0.1u καταστέλλουν κυρίως διακυμάνσεις υψηλής συχνότητας, ενώ οι 10uF λειτουργούν ως τοπικές αποθήκες ενέργειας περιορίζοντας τις διακυμάνσεις χαμηλότερων συχνοτήτων.

Τέλος, ως διεπαφή των ηλεκτροδίων με την πλακέτα επιλέχθηκε ένας απλός διπολικός ακροδέκτης (2-terminal connector) με βήμα 5mm. Στο Σχήμα 4.13 φαίνεται η τελική πλακέτα με όλα τα στοιχεία ενσωματωμένα.

\begin{figure}[H]
  \centering
  
  \caption{Η τελική μορφή της πλακέτας.}
  \label{fig:signal-buffering-filtering}
\end{figure}

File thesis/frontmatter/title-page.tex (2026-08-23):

\thispagestyle{empty}
\begin{center}
  \vspace*{0.35cm}
  

  \vspace{0.9cm}
  {\fontsize{16}{19}\selectfont \schoolgr\par}
  \vspace{0.45cm}
  {\fontsize{16}{20}\selectfont \departmentgr\par}

  \vfill
  {\fontsize{16}{19}\selectfont ΔΙΠΛΩΜΑΤΙΚΗ ΕΡΓΑΣΙΑ\par}

  \vfill
  \begin{minipage}[t]{0.46\textwidth}
    \raggedright\bfseries
    Της φοιτήτριας\\
    \studentnamecover\\
    Αριθμός Μητρώου: \studentid
  \end{minipage}%
  \hfill
  \begin{minipage}[t]{0.46\textwidth}
    \raggedleft\bfseries
    Επιβλέπων\\
    \supervisorcover\\
    ΒΑΘΜΙΔΑ\\
    \supervisorrank
  \end{minipage}

  \vfill
  {\bfseries \submissiondate\par}
\end{center}
\clearpage

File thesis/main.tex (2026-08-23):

% !TeX program = pdflatex
\documentclass{ihu-thesis}

\input{metadata}

\begin{document}

\input{frontmatter/title-page}
\frontmatter
\pagestyle{frontmatter}
\input{frontmatter/declaration}
\input{frontmatter/abstract-gr}
\input{frontmatter/abstract-en}

\tableofcontents
\clearpage
\addcontentsline{toc}{chapter}{Κατάλογος Σχημάτων}
\listoffigures
\clearpage
\addcontentsline{toc}{chapter}{Κατάλογος Πινάκων}
\listoftables
\clearpage

\mainmatter
\pagestyle{fancy}
\input{chapters/01-introduction}
\input{chapters/02-theoretical-background}
\input{chapters/03-electrical-characteristics}
\input{chapters/04-sensor-design}

\backmatter
\begingroup
\small
\setlength{\parindent}{0pt}
\input{bibliography/references-static}
\endgroup

\end{document}

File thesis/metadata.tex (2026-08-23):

\newcommand{\universitygr}{ΔΙΕΘΝΕΣ ΠΑΝΕΠΙΣΤΗΜΙΟ ΤΗΣ ΕΛΛΑΔΟΣ}
\newcommand{\schoolgr}{ΣΧΟΛΗ ΜΗΧΑΝΙΚΩΝ}
\newcommand{\departmentgr}{ΤΜΗΜΑ ΜΗΧΑΝΙΚΩΝ ΠΛΗΡΟΦΟΡΙΚΗΣ ΚΑΙ ΗΛΕΚΤΡΟΝΙΚΩΝ ΣΥΣΤΗΜΑΤΩΝ}

\newcommand{\thesistitlegr}{Σχεδίασης και ανάπτυξη συστήματος μέτρησης υγρασίας εδάφους}
\newcommand{\thesiscode}{23193}

\newcommand{\studentnamegr}{Μοσχοπούλου Παυλίνα}
\newcommand{\studentnamecover}{Μοσχοπούλου Παυλίνας}
\newcommand{\studentid}{2020096}

\newcommand{\supervisorname}{Αργύριος Χατζόπουλος}
\newcommand{\supervisorcover}{Χατζόπουλος Αργύριος}
\newcommand{\supervisorrank}{Αναπ. Καθηγητής}
\newcommand{\assignmentdate}{31-03-2025}
\newcommand{\completiondate}{}
\newcommand{\submissiondate}{Θεσσαλονίκη, 2026}

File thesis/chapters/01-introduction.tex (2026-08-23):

\chapter{Εισαγωγή}
\label{ch:introduction}

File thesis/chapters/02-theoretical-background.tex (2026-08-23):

\chapter{Θεωρητικό Υπόβαθρο Εδάφους και Υγρασίας}
\label{ch:theory}

\section{Φυσικές Ιδιότητες του Εδάφους και Μέθοδοι Μέτρησης Υγρασίας}

\subsection{Εισαγωγή}

Στο κεφάλαιο αυτό παρουσιάζονται οι βασικές έννοιες του εδάφους και
περιγράφονται οι κύριες φυσικές και χημικές του ιδιότητες. Επιπλέον,
παρουσιάζονται οι μορφές ύπαρξης του νερού εντός του εδάφους, καθώς και
οι βασικές μέθοδοι που χρησιμοποιούνται για τον υπολογισμό της
περιεκτικότητάς του σε νερό.

\subsection{Ορισμός και Χαρακτηριστικά Εδάφους}

Το έδαφος αποτελεί το ανώτερο στρώμα του γήινου φλοιού και απαρτίζεται
από στερεά υλικά (οργανική και ανόργανη ύλη), νερό και αέρια. Πρόκειται
για ένα δυναμικά μεταβαλλόμενο σύστημα που ορίζεται από πολλές φυσικές
παραμέτρους όπως η υφή, η θερμοκρασία, η αλατότητα και το pH \cite{ref01}.

\paragraph{Υφή}

Μία από τις σημαντικότερες ιδιότητες είναι η υφή του εδάφους. Ανάλογα με
τη σύσταση των ανόργανων υλικών (άμμος, ιλύς και άργυλος) τα εδάφη
ταξινομούνται σε μία από τις παρακάτω κατηγορίες υφής: αμμώδες (sandy),
ιλυώδες (silty), αργιλώδες (clayey), πηλώδες (loamy), αμμοπηλώδες (sandy
loam), πηλοαμμώδες (loamy sand), ιλυοπηλώδες (silty loam), αργιλοπηλώδες
(clay loam), ιλυοαργιλοπηλώδες (silty clay loam), αμμοαργιλοπηλώδες
(sandy clay loam), ιλυοαργιλώδες (silty clay), αμμοαργιλώδες (sandy
clay). \cite{ref02}

Η υφή του εδάφους θεωρείται σχετικά μόνιμο χαρακτηριστικό και επηρεάζει
σημαντικά τις ιδιότητες του, όπως τη συγκράτηση του νερού, τον αερισμό
αλλά και τη διείσδυση των ριζών. Για το λόγο αυτό είναι ιδιαίτερα
χρήσιμος ο χαρακτηρισμός του εδάφους στη γεωργία, καθώς διαδραματίζει
καθοριστικό ρόλο στην ανάπτυξη των φυτών.

\begin{figure}[H]
  \centering
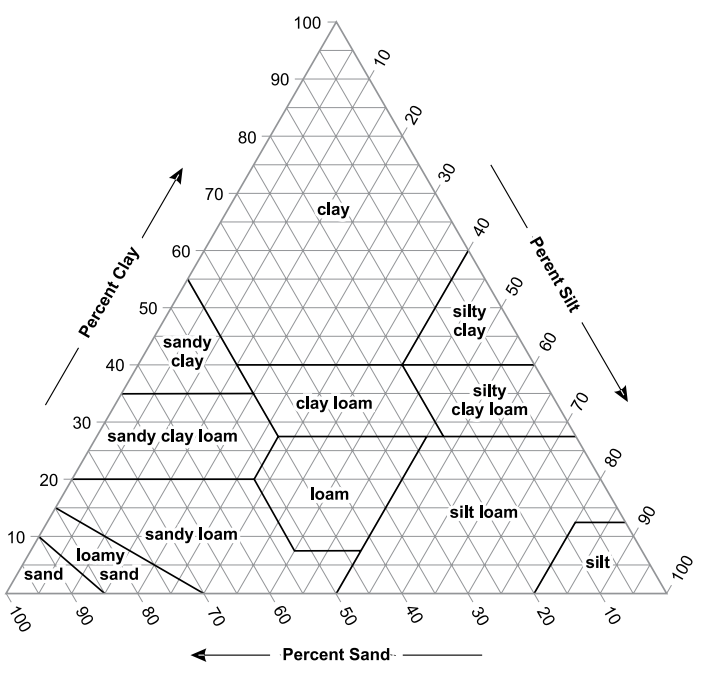
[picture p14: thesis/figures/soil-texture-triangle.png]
  
  \caption{Διάγραμμα υφής του USDA που απεικονίζει τις δώδεκα κατηγορίες υφής σύμφωνα με τα ποσοστά αργίλου, ιλύος και άμμου. \cite{ref01}}
  \label{fig:soil-texture-triangle}
\end{figure}

\paragraph{Τιμή pH}

Μία ακόμη χημική ιδιότητα είναι το pH, το οποίο εκφράζει πόσο όξινο ή
αλκαλικό είναι το έδαφος. Η γνώση του pH θεωρείται ιδιαίτερα σημαντική,
καθώς επηρεάζει τη διαθεσιμότητα των θρεπτικών συστατικών προς τα φυτά,
τη δραστηριότητα των μικροοργανισμών αλλά και τον καθορισμό της
καταλληλότητας του εδάφους για διαφορετικές καλλιέργειες. Η διαλυτότητα
και κατά συνέπεια η διαθεσιμότητα των διαφόρων χημικών στοιχείων
μεταβάλλεται ανάλογα με την τιμή του pH, καθορίζοντας έτσι το εύρος
τιμών στο οποίο μπορεί να ευδοκιμήσει κάθε καλλιέργεια, ανάλογα με τις
θρεπτικές της απαιτήσεις. \cite{ref07}

\paragraph{Αλατότητα}

Το έδαφος εκτός από τη στερεά μορφή του περιλαμβάνει και την υγρή φάση,
το επονομαζόμενο εδαφικό διάλυμα, στο οποίο συναντώνται διαλυμένα άλατα
με τη μορφή ιόντων. Τα κύρια στοιχεία είναι το άζωτο, ο φώσφορος και το
κάλιο. Τα ιόντα αυτά αποτελούν την άμεσα διαθέσιμη μορφή θρεπτικών
στοιχείων επηρεάζοντας τη γονιμότητά του \cite{ref02} . Εκτός από τις φυσικές
του ιδιότητες, τα ιόντα επηρεάζουν και τις ηλεκτρικές του ιδιότητες,
καθώς η ηλεκτρική αγωγιμότητα του εδάφους χρησιμοποιείται συνήθως ως
ένδειξη του πλήθους των διαλυμένων αλάτων. Το μέγεθος αυτό βοηθάει στην
εκτίμηση της ποιότητας του εδάφους, καθώς η παρουσία διαλυμένων αλάτων
είναι απαραίτητη για την ανάπτυξη των φυτών, ενώ σε υψηλές συγκεντρώσεις
μπορεί να μειώσουν τη διαθεσιμότητα του νερού \cite{ref09}.

\paragraph{Πορώδες}

Η παρουσία νερού στο έδαφος είναι κρίσιμη, καθώς είναι ο μηχανισμός
μεταφοράς των θρεπτικών ουσιών. Ένα μέρος αποθηκεύεται στους πόρους του
εδάφους κι ένα μέρος αποστραγγίζεται. Η διαθεσιμότητά του προς τα φυτά
εξαρτάται από το πόσο ισχυρά συγκρατείται από το εδαφικό υλικό. Στη
διαδικασία αυτή σημαντικό ρόλο διαδραματίζει η δομή του εδάφους, και
ειδικότερα το πόσο πορώδες είναι. Σε συμπιεσμένα εδάφη, περιορίζεται η
διήθηση του νερού και εμποδίζεται η ανάπτυξη του ριζικού συστήματος. Σε
ένα σωστά δομημένο έδαφος διευκολύνεται η κατάλληλη διήθηση και
αποστράγγιση του νερού, καθώς και η κυκλοφορία του αέρα. \cite{ref08}

\begin{figure}[H]
  \centering
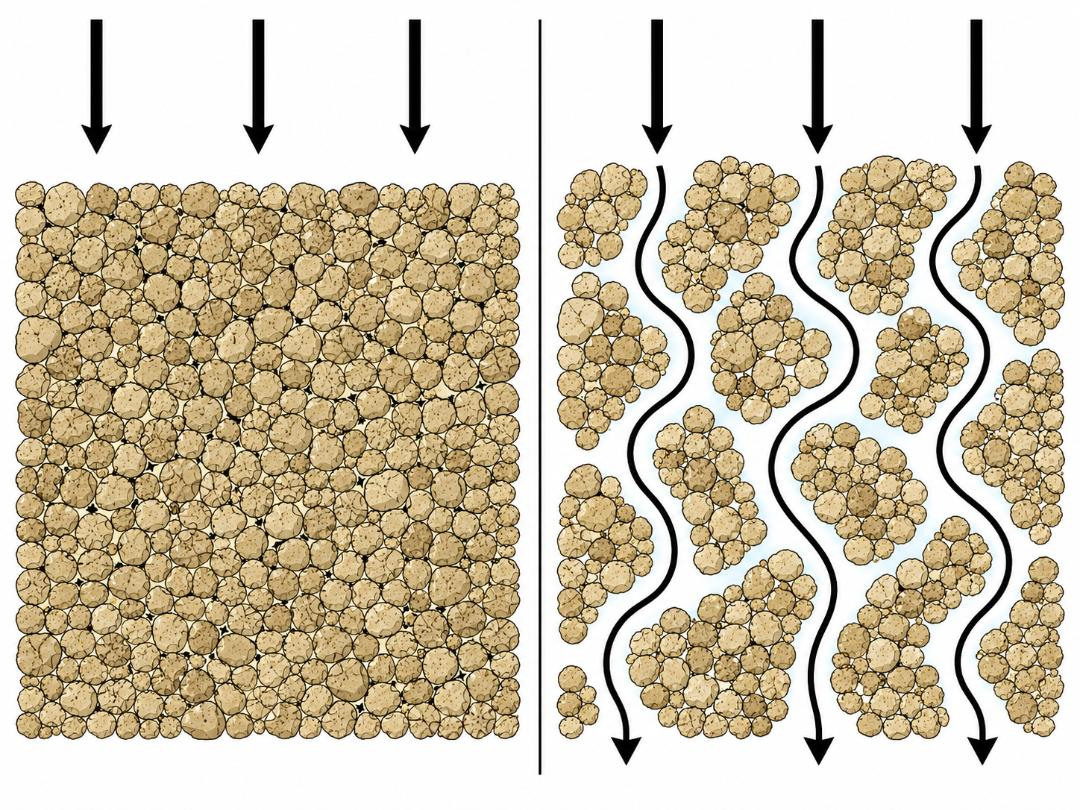
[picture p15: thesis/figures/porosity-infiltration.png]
  
  \caption{Διήθηση νερού σε έδαφος με μειωμένο και αυξημένο πορώδες αντίστοιχα.}
  \label{fig:porosity-infiltration}
\end{figure}

\subsection{Καταστάσεις νερού στο Έδαφος}

Η ύπαρξη νερού, αποτελεί μεταβλητή αλλά απαραίτητη ιδιότητα του εδάφους.
Στο εδαφικό διάλυμα η κατάσταση του νερού υπάρχει σε δύο βασικές μορφές,
το \textbf{Ελεύθερο Νερό} (Free Water) και το \textbf{Δεσμευμένο Νερό}
(Bound Water) οι οποίες απεικονίζονται στο \figref{fig:free-bound-water}. Όταν το νερό
βρεθεί κοντά στην επιφάνεια των κόκκων, ένα μέρος απορροφάται και
συγκρατείται ισχυρά από δυνάμεις προσρόφησης, αποτελώντας το δεσμευμένο
νερό. Σε αντίθεση με το ελεύθερο, το δεσμευμένο έχει μειωμένη
κινητικότητα και δε μπορεί εύκολα να προσανατολιστεί όταν εφαρμοστεί
ηλεκτρικό πεδίο \cite{ref03,ref04}.

\begin{figure}[H]
  \centering
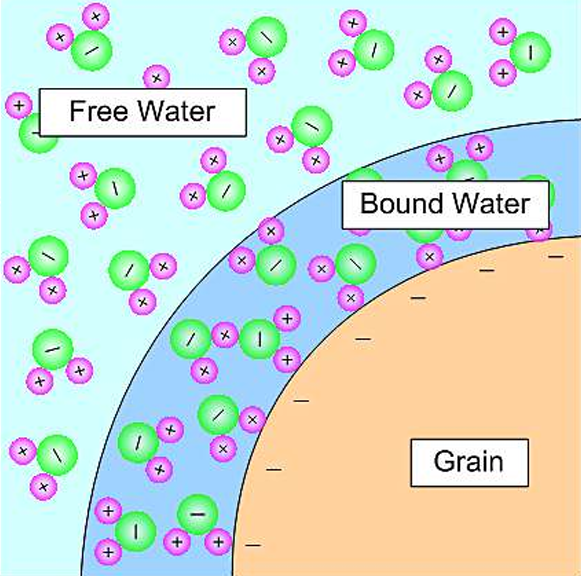
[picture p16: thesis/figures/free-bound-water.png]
  
  \caption{Διαχωρισμός του νερού στο έδαφος σε Ελεύθερο Νερό και Δεσμευμένο νερό. \cite{ref04}}
  \label{fig:free-bound-water}
\end{figure}

Το νερό, όπως και κάθε υλικό, χαρακτηρίζεται από τη \textbf{διηλεκτρική
σταθερά}, ένα μέγεθος ιδιαίτερα χρήσιμο για τον προσδιορισμό της
ποσότητας νερού στο έδαφος. Η διηλεκτρική σταθερά εξαρτάται από την
ικανότητά του υλικού να πολώνεται υπό την επίδραση ηλεκτρικού πεδίου .
Ως αποτέλεσμα, το ελεύθερο νερό έχει μεγαλύτερη διηλεκτρική σταθερά σε
σχέση με το δεσμευμένο νερό, τα μόρια του οποίου ευθυγραμμίζονται
δυσκολότερα με το πεδίο \cite{ref04}. Η ποσότητα του νερού που θα δεσμευθεί
εξαρτάται άμεσα και από τον τύπο του εδάφους, με ενδεικτικό παράδειγμα
τα αργιλώδη εδάφη να συγκρατούν περισσότερο νερό συγκριτικά με τα αμμώδη
λόγω της μεγαλύτερης επιφάνειας των κόκκων\cite{ref03}.

\subsection{Έκφραση της Περιεκτικότητας του Εδάφους σε Νερό}

Η περιεκτικότητα του εδάφους σε νερό εκφράζεται με δύο βασικά μεγέθη:
την \textbf{βαρυμετρική} περιεκτικότητα σε νερό (Gravimetric Water
Content ή GWC) και την \textbf{ογκομετρική} περιεκτικότητα σε νερό
(Volumetric Water Content ή VWC).

Η βαρυμετρική περιεκτικότητα σε νερό είναι η μάζα του νερού ανά μονάδα
μάζας εδάφους, δηλαδή γραμμάρια νερού ανά γραμμάρια εδάφους και
υπολογίζεται σύμφωνα με τον παρακάτω τύπο

\[w = \frac{M_{moist}\,(g) - M_{dry}\,(g)}{M_{dry}\,(g)}\]

Για τον υπολογισμό του ζυγίζεται αρχικά ένα δείγμα υγρού εδάφους και στη
συνέχεια εφόσον ξηρανθεί και έχει εξατμιστεί όλη η ποσότητα του νερού,
πραγματοποιείται και πάλι η ζύγιση του δείγματος. Αποτελεί μία από τις
κύριες μεθόδους για τον υπολογισμό της υγρασίας καθώς η ποσότητα του
νερού υπολογίζεται απευθείας με τη μέτρηση των μαζών. \cite{ref05}

Η \textbf{ογκομετρική περιεκτικότητα} σε νερό ορίζεται ως ο όγκος του
νερού προς το συνολικό όγκο του εδαφικού δείγματος, όπως φαίνεται από
τον παρακάτω τύπο

\[\theta = \frac{V_{water}\,\left( m^{3} \right)}{V_{soil}\,\left( m^{3} \right)}\]

Η ογκομετρική περιεκτικότητα προκύπτει είτε έμμεσα από τη βαρυμετρική,
είτε χρησιμοποιείται κάποιος αισθητήρας για τον υπολογισμό της. Οι
αισθητήρες αυτοί αξιοποιούν τις διηλεκτρικές ιδιότητες του νερού, αφού
το νερό λόγω της υψηλής διηλεκτρικής σταθεράς του θα αλληλεπιδράσει
έντονα με το ηλεκτρομαγνητικό πεδίο που εφαρμόζεται στο δείγμα από τον
αισθητήρα. Τελικά, σύμφωνα με την απόκριση των μορίων του νερού στο
πεδίο γίνεται η εκτίμηση της ογκομετρικής υγρασίας. \cite{ref06}

Η βαρυμετρική και η ογκομετρική περιεκτικότητα εκφράζουν το ίδιο φυσικό
μέγεθος, με το w να βασίζεται στη μάζα ενώ το θ στον όγκο. Συσχετίζοντας
τα δύο μεγέθη, η ογκομετρική περιεκτικότητα μπορεί να εκφραστεί ως το
γινόμενο της βαρυμετρικής με τη φαινόμενη ξηρή πυκνότητα του εδάφους
ρ\textsubscript{b} (dry bulk density)

\[\theta = w\,\rho_{b}\]

όπου ρ\textsubscript{b} ορίζεται ως ο λόγος της μάζας του ξηρού εδάφους
(m\textsubscript{d}) προς το συνολικό όγκο του εδαφικού δείγματος (
V\textsubscript{soil} ) \cite{ref05,ref06}

\[\rho_{b} = \frac{m_{d}\,(g)}{V_{soil}\,\left( cm^{3} \right)}\]

\section{Ηλεκτρομαγνητική Συμπεριφορά Εδάφους}

\subsection{Εισαγωγή}

Το χώμα αποτελεί ένα ετερογενές και πορώδες υλικό. Η ηλεκτρομαγνητική
συμπεριφορά ενός μη-σιδηρομαγνητικού υλικού, όπως και του εδάφους,
μπορεί να παρομοιαστεί ως ένας πυκνωτής με απώλειες (lossy capacitor).
Το σήμα που περνάει μέσα από το χώμα θα υποστεί ιοντικές απώλειες οι
οποίες οφείλονται σε διαλυμένα άλατα (Na,Cl) τα οποία κινούνται ελεύθερα
υπό την επίδραση του πεδίου. Έτσι, εμφανίζεται η αγωγιμότητα που
οφείλεται στο ρεύμα μέσω της πραγματικής μεταφοράς ηλεκτρικού φορτίου
\cite{ref10}.

Παράλληλα, τα μόρια του νερού λόγω της διπολικότητάς τους, θα
προσπαθήσουν να ευθυγραμμιστούν με το εναλλασσόμενο πεδίο. Αυτό δίνει
στο μέσο έναν διηλεκτρικό χαρακτήρα, ο οποίος θα εμφανίσει το ρεύμα
μετατόπισης \cite{ref10}.

Στο παρόν κεφάλαιο, θα αναλυθούν οι δύο συνιστώσες που καθορίζουν την
ηλεκτρομαγνητική απόκριση του εδάφους και είναι χρήσιμες για τον
προσδιορισμό σημαντικών φυσικών παραμέτρων: η αγώγιμη και τη διηλεκτρική
συνιστώσα .

\subsection{Αγωγιμότητα και Ειδική Αντίσταση -- Μέθοδος Wenner}

Ως ηλεκτρική αντίσταση ενός αγωγού ορίζεται η δυσκολία που παρουσιάζει
στη διέλευση του ηλεκτρικού ρεύματος, κι εκφράζεται από το νόμο του Οhm
ως:

\[R = \frac{V}{I},\quad(\Omega)\]

όπου V είναι η διαφορά δυναμικού στα άκρα του αγωγού σε Volt και I η
ένταση του ρεύματος σε Ampere. Επειδή ωστόσο η αντίσταση εξαρτάται άμεσα
από τη γεωμετρία του αγωγού, εκφράζεται επίσης από τη σχέση:

\[R = \rho\frac{L}{A},\quad(\Omega)\]

όπου ρ η ειδική αντίσταση του αγωγού σε Ω*m, L το μήκος του αγωγού και Α
το εμβαδό της διατομής του. Το αντίστροφο της αντίστασης ονομάζεται
ηλεκτρική αγωγιμότητα και συμβολίζεται ως \cite{ref14}:

\[G = \frac{1}{R},\quad(Siemens)\]

ενώ το αντίστροφο της ειδικής αντίστασης ονομάζεται ειδική ηλεκτρική
αγωγιμότητα και συμβολίζεται ως \cite{ref13}:

\[\sigma = \frac{1}{\rho},\quad(Siemens/m)\]

Η ειδική ηλεκτρική αγωγιμότητα χρησιμοποιείται συχνά ως δείκτης για τη
συγκέντρωση των διαλυμένων αλάτων στο έδαφος (αλατότητα). Η αγωγιμότητα
του εδάφους συμβολίζεται ως EC και εκφράζεται σε Siemens/m.

Μία διαδεδομένη μέθοδος μέτρησης της αλατότητας του εδάφους στηρίζεται
στον υπολογισμό της ειδικής αντίστασης με τη μέθοδο Wenner. Κατά τη
μέθοδο αυτή, χρησιμοποιούνται τέσσερα ηλεκτρόδια που τοποθετούνται στο
έδαφος σε ευθεία γραμμή σε ίσες συνήθως μεταξύ τους αποστάσεις
(\figref{fig:wenner-array}). Στο ζευγάρι των εξωτερικών ηλεκτροδίων γίνεται η έγχυση
ρεύματος, ενώ το εσωτερικό ζευγάρι χρησιμοποιείται για τη μέτρηση της
διαφοράς δυναμικού \cite{ref15}.

\begin{figure}[H]
  \centering
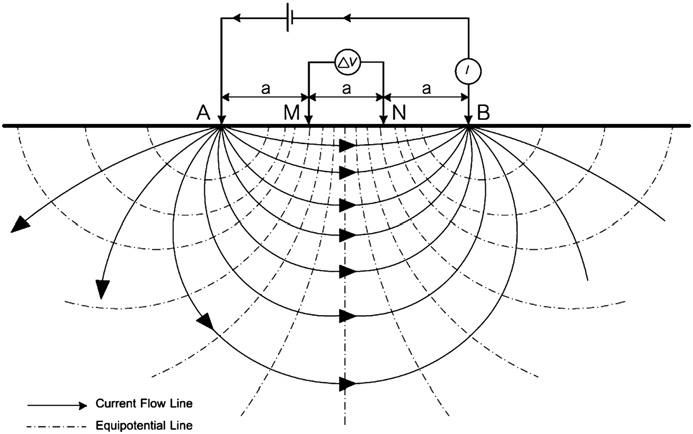
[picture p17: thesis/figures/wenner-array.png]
  
  \caption{Η διάταξη Wenner με τα τέσσερα ηλεκτρόδια A, M, N και Β σε απόσταση a, τις ισοδυναμικές γραμμές και τη ροή του ρεύματος εξ αιτίας του ηλεκτρομαγνητικού πεδίου. Το ρεύμα ρέει από τα εξωτερικά ηλεκτρόδια, ενώ η πτώση τάσης μετράται από τα εσωτερικά. \cite{ref14}}
  \label{fig:wenner-array}
\end{figure}

Επειδή η πραγματική ειδική αντίσταση του μέσου θα διαφέρει από τη
μέτρηση, χρησιμοποιείται ο συμβολισμός της φαινόμενης ειδικής αντίστασης
ρ\textsubscript{α}. Για απόσταση a και βάθος c, ο τύπος που δίνει το
ρ\textsubscript{α} είναι \cite{ref11}:

\[\rho_{\alpha} = \frac{4\pi\alpha R}{1 + \frac{2\alpha}{\sqrt{\alpha^{2} + 4c^{2}}} - \frac{\alpha}{\sqrt{\alpha^{2} + c^{2}}}}\]

Επομένως,

\[EC_{\alpha} = \sigma_{\alpha} = \frac{1}{\rho_{\alpha}} = \frac{1 + \frac{2\alpha}{\sqrt{\alpha^{2} + 4c^{2}}} - \frac{\alpha}{\sqrt{\alpha^{2} + c^{2}}}}{4\pi\alpha R}\]

Εάν θεωρήσουμε το βάθος των ηλεκτροδίων πολύ μικρότερο από τη μεταξύ
τους απόσταση, ο παραπάνω τύπος μπορεί να απλοποιηθεί ως εξής \cite{ref12}:

\[\rho_{\alpha} = 2\pi\alpha R\]

\subsection{Θεωρία των Διηλεκτρικών}

\textbf{Διηλεκτρικά} ονομάζονται τα υλικά που είναι μη αγώγιμα στο
ηλεκτρικό ρεύμα, αλλά χαρακτηρίζονται από την ικανότητα των δεσμευμένων
ηλεκτρικών φορτίων τους να \textbf{πολώνονται} όταν εκτίθενται σε
ηλεκτρικό πεδίο. Πρακτικά, η ροή του ρεύματος είναι μικρή ή σχεδόν
μηδενική ενώ η ενέργεια αποθηκεύεται στο ηλεκτρικό πεδίο που
δημιουργείται εντός του διηλεκτρικού λόγω της πόλωσης. \textbf{Ηλεκτρική
Πόλωση (P)} είναι το μέγεθος που εκφράζει το βαθμό διαχωρισμού των
θετικών και αρνητικών φορτίων ενός υλικού όταν αυτό εκτεθεί σε ηλεκτρικό
πεδίο \cite{ref17}.

Η ικανότητα αυτή ενός συστήματος να αποθηκεύει ηλεκτρικό φορτίο
εκφράζεται από τη \textbf{χωρητικότητα}. Πιο συγκεκριμένα, πρόκειται για
το μονόμετρο φυσικό μέγεθος που συναντάται συνήθως στους πυνκωτές και
ορίζεται ως το πηλίκο του ηλεκτρικού φορτίου Q του πυκνωτή ως προς την
τάση V μεταξύ των οπλισμών του πυκνωτή \cite{ref15},

\[C = \frac{Q\,(Coulomb)}{V\,(Volt)},\quad Farad\]

Ο παραπάνω τύπος εφαρμόζεται για κάθε μορφής πυκνωτή, ωστόσο η
χωρητικότητα εξαρτάται από το σχήμα, τις διαστάσεις, την απόσταση των
οπλισμών, καθώς και το διηλεκτρικό που παρεμβάλλεται μεταξύ των
οπλισμών. Γι'αυτό το λόγο, για έναν επίπεδο πυκνωτή με αέρα ή κενό ως
διηλεκτρικό, η χωρητικότητα δίνεται από τη σχέση \cite{ref28}

\[C = \frac{\varepsilon_{0}\, A}{d},\quad F\quad\quad\text{(10)}\]

όπου $\varepsilon_{0}=8{,}85\cdot 10^{-12}\,\mathrm{C^2/(N\,m^2)}$ η \textbf{απόλυτη
διηλεκτρική σταθερά} του κενού, Α το εμβαδόν του οπλισμού και d η
απόσταση των οπλισμών. Η \textbf{απόλυτη διηλεκτρική σταθερά ή απόλυτη
διηλεκτρική διαπερατότητα} αποτελεί ένα μέγεθος το οποίο εκφράζει την
ικανότητα ενός διηλεκτρικού υλικού να πολώνεται στο εσωτερικό του όταν
εφαρμοστεί ηλεκτρικό πεδίο. Ειδικότερα, ορίζεται ως ο λόγος της
ηλεκτρικής μετατόπισης \(\overrightarrow{D}\)
\(\left( \frac{C}{m^{2}} \right)\) προς το ηλεκτρικό πεδίο
\(\overrightarrow{E}\left( \frac{V}{m} \right)\) στο εσωτερικό του
\cite{ref16}

\[\varepsilon = \frac{\overrightarrow{D}}{\overrightarrow{E}},\quad F/m\]

Εάν μεταξύ των οπλισμών υπάρχει διηλεκτρικό υλικό, τότε η εξίσωση (10)
μετατρέπεται σε \cite{ref15,ref28}

\[C = \frac{\varepsilon_{0}\,\varepsilon_{r}\, A}{d},\quad F\]

όπου ε\textsubscript{r} η \textbf{σχετική διηλεκτρική σταθερά ή σχετική
διηλεκτρική διαπερατότητα} του υλικού.

Η εισαγωγή του διηλεκτρικού έχει ως αποτέλεσμα την αύξηση της
χωρητικότητας συγκριτικά με την ύπαρξη κενού. Αυτό συμβαίνει λόγω της
πόλωσης των φορτίων του υλικού, τα οποία δημιουργούν εσωτερικό πεδίο
αντίθετης φοράς από το εφαρμοζόμενο πεδίο. Το μέτρο της απόκρισης ενός
υλικού στο εφαρμοζόμενο πεδίο χαρακτηρίζεται από τη \textbf{σχετική
διηλεκτρική σταθερά} (relative dielectric constant) \textbf{ή}
\textbf{σχετική διηλεκτρική διαπερατότητα} (relative dielectric
permittivity) και λαμβάνει μία δεδομένη τιμή που εξαρτάται από το
εκάστοτε υλικό \cite{ref15}.

Η σχετική διηλεκτρική σταθερά συνδέεται με την απόλυτη διηλεκτρική
σταθερά μέσω της σχέσης \cite{ref15}

\[\varepsilon_{r} = \frac{\varepsilon}{\varepsilon_{0}}\]

\begin{figure}[H]
  \centering
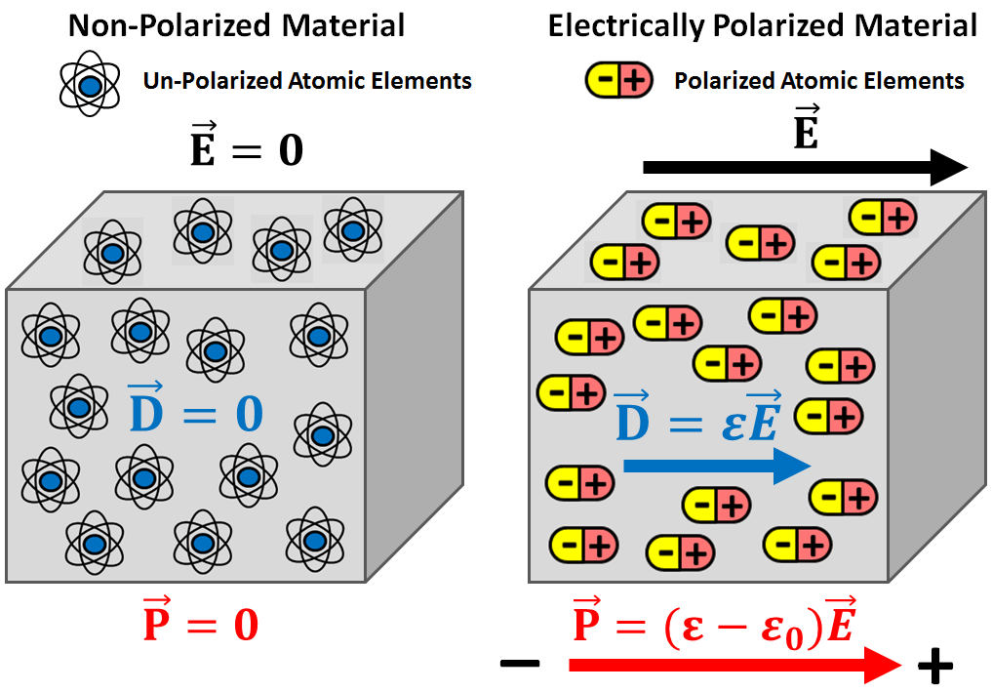
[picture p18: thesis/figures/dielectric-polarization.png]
  
  \caption{Απεικόνιση του μη πολωμένου υλικού απούσια εξωτερικού πεδίου στα αριστερά. Στα δεξιά απεικονίζεται η πόλωση των διπόλων του υλικού κατά την εφαρμογή ηλεκτρικού πεδίου, με την πόλωση να δίνεται ως \(\overrightarrow{P} = \left( \varepsilon-\varepsilon_{0} \right) \cdot \overrightarrow{E}\) . \cite{ref16}}
  \label{fig:dielectric-polarization}
\end{figure}

\subsection{Μη ιδανικά Διηλεκτρικά}

Σε μη ιδανικά διηλεκτρικά, όπως και το έδαφος, ταυτόχρονα με την πόλωση
παρουσιάζονται και αγώγιμες απώλειες οι οποίες τελικά μετατρέπονται σε
θερμότητα. Η συνολική αυτή απόκριση του διηλεκτρικού σε εναλλασσόμενο
πεδίο μπορεί να περιγραφεί από την \textbf{απόλυτη} \textbf{ηλεκτρική
μιγαδική διαπερατότητα ε* (absolute permittivity)} \cite{ref18}:

\[\varepsilon^{*}(\omega) = \varepsilon'(\omega) + j\varepsilon_{eff}''(\omega)\]

και συνδέεται με τη σχετική διηλεκτρική διαπερατότητα με τη σχέση:

\[\varepsilon^{*}(\omega) = \varepsilon_{0}\,\varepsilon_{r}^{*}(\omega)\]

όπου \(\varepsilon_{0}\) η ηλεκτρική διαπερατότητα του κενού. Από τα
παραπάνω προκύπτει η μιγαδική \textbf{σχετική ηλεκτρική διαπερατότητα} η
οποία αποτελεί αδιάστατο μέγεθος και περιγράφει την αλληλεπίδραση ενός
υλικού σε σχέση με το πεδίο \cite{ref18,ref19}:

\[\varepsilon_{r}(\omega) = \varepsilon_{r}'(\omega) + j\varepsilon_{r,eff}''(\omega)\]

To εr'(ω) αποτελεί το πραγματικό μέρος της μιγαδικής διαπερατότητας και
εκφράζει το ποσό της ενέργειας που έχει αποθηκευτεί στο υλικό από το
εξωτερικό πεδίο. Το ε'\,'reff(ω) αποτελεί το φανταστικό μέρος και
σχετίζεται με τις διηλεκτρικές και θερμικές απώλειες. Στα μη ιδανικά
διηλεκτρικά όπου συνυπάρχουν οι απώλειες λόγω πόλωσης και ηλεκτιρκής
αγωγιμότητας, εκφράζονται ως \cite{ref18,ref19}:

\[\varepsilon_{r,eff}''(\omega) = \varepsilon_{r,d}''(\omega) + \frac{\sigma}{\omega\,\varepsilon_{0}}\]

όπου σ(S/m) η DC αγωγιμότητα και ε\textsubscript{rd}'\,' το φανταστικό
μέρος της σχετικής διαπερατότητας που εκφράζει τις απώλειες λόγω των
μηχανισμών πόλωσης. Επειδή, ωστόσο, στους περισσότερους τύπους εδαφών το
ε\textsubscript{rd}'\,' μπορεί να θεωρηθεί σχετικά μικρό, η μέτρηση του
φανταστικού μέρους χρησιμοποιείται συχνά για την εκτίμηση της
αγωγιμότητας σε συχνότητες στην περιοχή των MHz \cite{ref19}. Επομένως,
λαμβάνοντας υπόψη ότι τα μεγέθη αυτά εξαρτώνται από τη συχνότητα, χάριν
απλούστευσης χρησιμοποιείται η έκφραση:

\[\varepsilon_{r}^{*} = \varepsilon_{r}' + j\varepsilon_{r}''\]

\[\varepsilon_{r}'' = \frac{\sigma}{\omega\,\varepsilon_{0}}\]

\subsection{Το Υγρό Έδαφος ως Διηλεκτρικό}

Το μόριο του νερού αποτελείται από ένα άτομο οξυγόνου (Ο) το οποίο φέρει
μερικό αρνητικό φορτίο (δ-) και δύο άτομα υδρογόνου (Η) τα οποία φέρουν
μερικό θετικό φορτίο. Λόγω της γωνιακής του δομής και της
ηλεκτραρνητικότερης φύσης του οξυγόνου, δημιουργείται ένα μόνιμο
ηλεκτρικό δίπολο όπως φαίνεται στο \figref{fig:water-dipole} \cite{ref19}

\begin{figure}[H]
  \centering
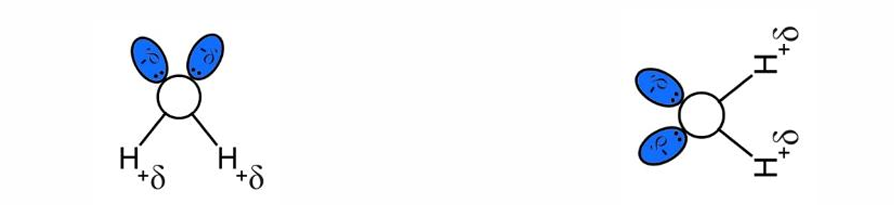
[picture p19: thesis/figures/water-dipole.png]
  
  \caption{Το διπολικό μόριο του νερού με τις μερικές φορτίσεις (δ+ και δ-). \cite{ref19}}
  \label{fig:water-dipole}
\end{figure}

Με την εφαρμογή εναλλασσόμενου ηλεκτρικού πεδίου, το δίπολο
περιστρέφεται ώστε να ευθυγραμμιστεί με το πεδίο. Στην περιοχή
συχνοτήτων MHz έως και χαμηλά GHz, τα μόρια του νερού ακολουθούν τις
ηλεκτρομαγνητικές ταλαντώσεις του πεδίου, ενώ τα σωματίδια του εδάφους
παραμένουν κατά κύριο λόγο ακλόνητα. Η συμπεριφορά αυτή δικαιολογεί τη
σημαντικά υψηλότερη σχετική διηλεκτρική σταθερά του νερού (περίπου 80
στους 25\textsuperscript{ο}) σε σύγκριση με αυτή των στερεών συστατικών
του εδάφους (περίπου 4-5 στους 25\textsuperscript{ο}) \cite{ref19}
(\figref{fig:soil-component-permittivity}).

\begin{figure}[H]
  \centering
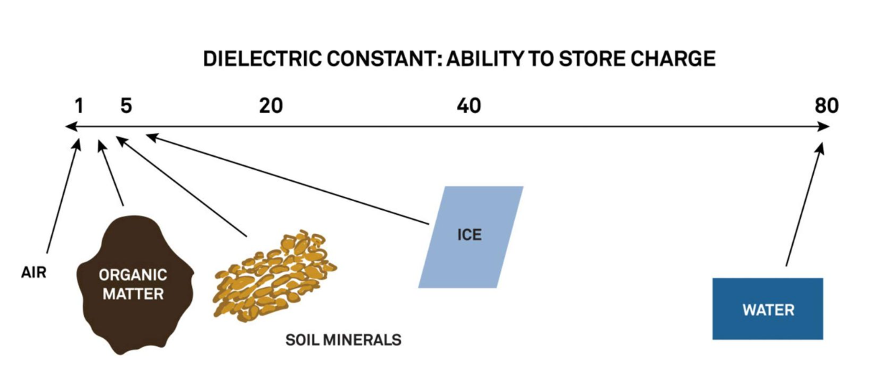
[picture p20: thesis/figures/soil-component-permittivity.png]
  
  \caption{Σχετική διηλεκτρική σταθερά των κύριων συστατικών του εδάφους και του νερού. \cite{ref21}}
  \label{fig:soil-component-permittivity}
\end{figure}

Οι περισσότεροι σύγχρονοι αισθητήρες βασίζονται σε αυτή την ιδιότητα των
μορίων του νερού προκειμένου να υπολογίσουν την περιεκτικότητά του σε
ένα δείγμα εδάφους. Συνεπώς, το μέγεθος που χρησιμοποιείται για την
εκτίμηση της υγρασίας στο έδαφος είναι το πραγματικό μέρος της σχετικής
διαπερατότητας ε'\textsubscript{r}. Η προσθήκη νερού στο έδαφος αυξάνει
σημαντικά τη συνολική ικανότητα του μέσου να αποθηκεύει ενέργεια μέσω
των μορίων του νερού, φαινόμενο που αντικατοπτρίζεται από την πραγματική
συνιστώσα ε'r.

Αντίθετα, το ε'\,' αποτελεί τη φανταστική συνιστώσα και όπως αναφέρθηκε
συνδέεται με τις απώλειες ενέργειας του μέσου. Συνδέεται στενά με το σ
μέσω της εξίσωσης~(2.1) και αντικατοπτρίζει την αγωγιμότητα λόγω της
ροής ελεύθερων ιόντων. Οι δύο συνιστώσες εξαρτώνται από τη συχνότητα.
Στο \figref{fig:permittivity-vs-frequency} φαίνεται η συμπεριφορά των εr' και εr΄΄ ενός μη ιδανικού
διηλεκτρικού που περιέχει αγώγιμα μονοπάτια, όπως το έδαφος.

\begin{figure}[H]
  \centering
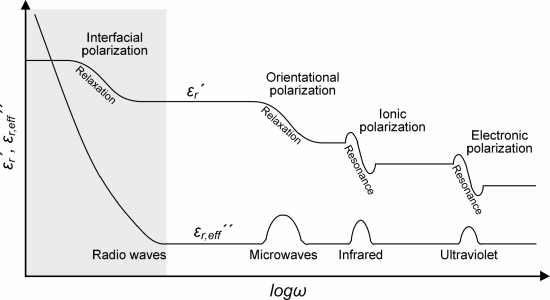
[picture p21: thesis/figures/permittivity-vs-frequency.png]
  
  \caption{Μεταβολή της πραγματικής και φανταστικής συνιστώσας της σχετικής διαπερατότητας και περιοχές εμφάνισης των μηχανισμών πόλωσης σε συνάρτηση με τη γωνιακή συχνότητα. \cite{ref18}}
  \label{fig:permittivity-vs-frequency}
\end{figure}

Το έδαφος αποτελείται από στερεά και υγρά σώματα, αέρα και άλατα, με
αποτέλεσμα η ροή του ρεύματος και η πόλωση των μορίων να μην είναι ίδια
σε όλο το φάσμα συχνοτήτων. Έτσι, στη διαμόρφωση της ηλεκτρικής
μιγαδικής διαπερατότητας συμβάλλει ένα σύνολο από μηχανισμούς πολώσεων.
Στο γράφημα παρουσιάζονται τέσσερις κύριοι μηχανισμοί \cite{ref20}:

\begin{itemize}
\item
  H διεπιφανειακή πόλωση (Interfacial Polarization) που σχετίζεται με τη
  συσσώρευση\\
  φορτίων σε διεπιφάνειες περιοχών λόγω της ανομοιογένειας του μέσου
\item
  Η διπολική πόλωση (Orientational Polarization) λόγω περιστροφής
  μόνιμων δίπολων όπως το νερό
\item
  Η ιοντική πόλωση (ionic polarization) λόγω ταλάντωσης των ιόντων του
  υλικού
\item
  Η ηλεκτρονική πόλωση (electronic polarization) που συμβαίνει σε
  ουδέτερα άτομα όταν
\item
  το ηλεκτρικό πεδίο μετατοπίζει των πυρήνα σε σχέση με τα ηλεκτρόνια
  που τον περιβάλλουν
\end{itemize}

Στις χαμηλές συχνότητες η απόκριση του εδάφους επηρεάζεται έντονα από
την ιοντική αγωγιμότητα που οφείλεται στην πραγματική μεταφορά ιόντων
κυρίως μέσα στο νερό των πόρων. Η αγώγιμη αυτή απώλεια, αποτυπώνεται στο
ε'\,'reff. Όπως αποτυπώνεται και από τον όρο σ/(ω*εο), η επίδραση της
αγωγιμότητας είναι μεγαλύτερη στις χαμηλότερες συχνότητες και μειώνεται
όσο αυξάνει η συχνότητα. Για το λόγο αυτό, η χαμηλή περιοχή συχνοτήτων
είναι ιδιαίτερα ευαίσθητη στην αγώγιμη συμπεριφορά του εδάφους και
χρησιμοποιείται συνήθως για την εκτίμηση της αλατότητας. Ωστόσο, στη
χαμηλή περιοχή συχνοτήτων συνυπάρχει και η διεπιφανειακή πόλωση, ενώ με
την αύξηση της συχνότητας ο μηχανισμός δεν προλαβαίνει να ακολουθήσει το
πεδίο κι εξασθενεί \cite{ref18,ref20}.

Από την άλλη, το ε' εμφανίζει υψηλές τιμές σε χαμηλές συχνότητες, καθώς
τα κινητά φορτία έχουν το χρόνο να μετακινηθούν και να και να
συσσωρευτούν στις διαφορετικές διεπιφάνειες του ανομοιογενές μέσου
δημιουργώντας χωρητικά φαινόμενα (διεπιφανειακή πόλωση). Αντίθετα, σε
υψηλότερες συχνότητες ο μηχανισμός αυτός δε δύναται να ακολουθήσει το
πεδίο κι εξασθενεί, μειώνοντας το ε'. Έτσι, αναδεικνύεται και
απομονώνεται καλύτερα η ικανότητα του υλικού να αποθηκεύει ενέργεια
κυρίως μέσω της πόλωσης των μορίων του νερού και διευκολύνει την
εκτίμηση του εr' (διπολική πόλωση).

Σε ακόμη υψηλότερες συχνότητες, έξω από το συνηθισμένο εύρος μέτρησης
υγρασίας, λαμβάνουν χώρα άλλοι μηχανισμοί όπως η ιοντική και ηλεκτρονική
πόλωση \cite{ref18,ref20}.

\begin{figure}[H]
  \centering
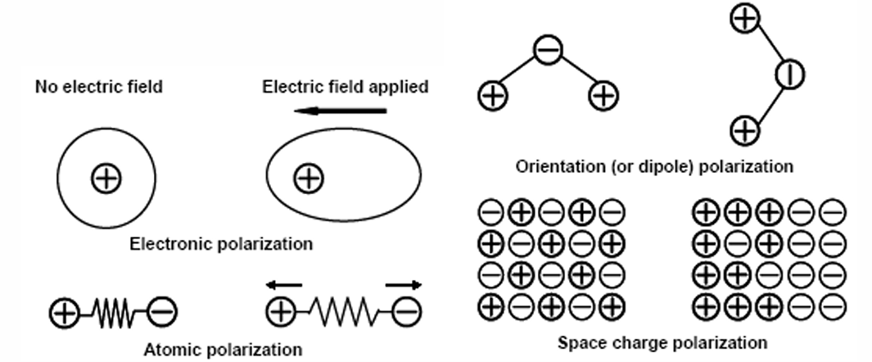
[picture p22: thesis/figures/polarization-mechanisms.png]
  
  \caption{Σχηματική απεικόνιση μηχανισμών πόλωσης σε διηλεκτρικό υλικό σε μικροσκοπικό επίπεδο. \cite{ref19}}
  \label{fig:polarization-mechanisms}
\end{figure}

\subsection{Μέθοδοι Μέτρησης της Υγρασίας Εδάφους με τη χρήση Αισθητήρων}

Η ανάπτυξη των αισθητήρων υγρασίας βασίζεται κυρίως στην εφαρμογή
ηλεκτρικού πεδίου και στην αλληλεπίδραση των μορίων του νερού με αυτό.
Κάποιες από τις κύριες τεχνολογίες που αξιοποιούν την αρχή αυτή
παρουσιάζονται παρακάτω.

Οι αισθητήρες \textbf{TDR} (Time Domain Reflectometry) λειτουργούν
σύμφωνα με τον υπολογισμό του χρόνου που χρειάζεται ένας
ηλεκτρομαγνητικός παλμός για να διαδοθεί κατά μήκος δύο ή τριών συνήθως
μεταλλικών ράβδων τοποθετημένων στο δείγμα, οι οποίες λειτουργούν ως
γραμμή μεταφοράς. Η ταχύτητα διάδοσης του παλμού εξαρτάται από τη
διηλεκτρική διαπερατότητα του δείγματος, η οποία επηρεάζεται άμεσα από
την περιεκτικότητά του σε νερό. Τελικά, από τη διηλεκτρική διαπερατότητα
εκτιμάται η ογκομετρική περιεκτικότητα μέσω εμπειρικών σχέσεων
βαθμονόμησης. Στο \figref{fig:tdr-setup} φαίνεται η πειραματική διάταξη και στο
\figref{fig:tdr-waveform} φαίνεται η διάδοση του αρχικού παλμού και του ανακλόμενου
σήματος. \cite{ref23}

\begin{figure}[H]
  \centering
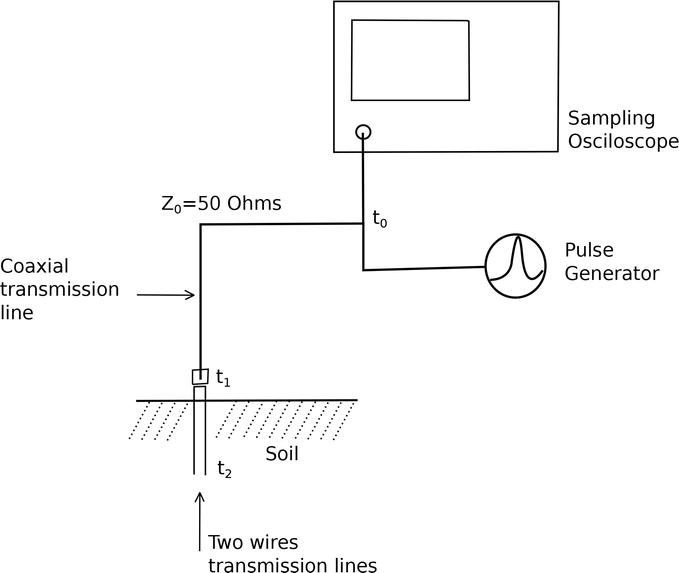
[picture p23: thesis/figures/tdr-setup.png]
  
  \caption{Πειραματική διάταξη για τη μέτρηση υγρασίας στο πεδίο του χρόνου με TDR. \cite{ref23}}
  \label{fig:tdr-setup}
\end{figure}

\begin{figure}[H]
  \centering
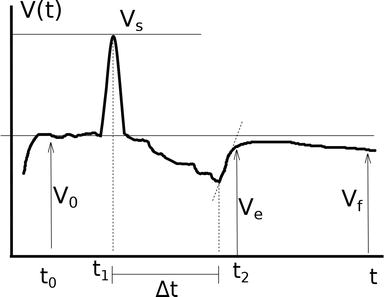
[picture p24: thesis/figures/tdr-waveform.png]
  
  \caption{Διάδοση του αρχικού παλμού και του ανακλώμενου σήματος κατά τη μέτρηση με αισθητήρα TDR. \cite{ref23}}
  \label{fig:tdr-waveform}
\end{figure}

Μία ακόμη μέθοδος είναι η \textbf{FDR} (Frequency Domain Reflectometry)
η οποία βασίζεται στη μέτρηση του συντελεστή ανάκλασης ενός
ηλεκτρομαγνητικού κύματος στο πεδίο της συχνότητας. Με τη χρήση ενός
Αναλυτή Διανυσματικών Δικτύων (Vector Network Analyzer), το δείγμα
διεγείρεται από ένα ηλεκτρομαγνητικό σήμα μεταβαλλόμενης συχνότητας και
καταγράφεται το πλάτος και η φάση (\figref{fig:fdr-vna-setup}). \cite{ref23}

\begin{figure}[H]
  \centering
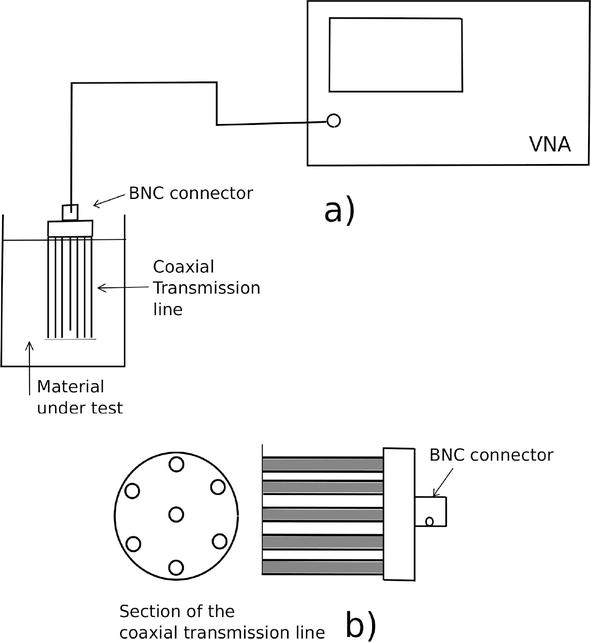
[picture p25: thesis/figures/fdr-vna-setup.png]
  
  \caption{Πειραματική διάταξη για τη μέτρηση υγρασίας στο πεδίο της συχνότητας (FDR) με Αναλυτή Διανυσματικών Δικτύων. \cite{ref23}}
  \label{fig:fdr-vna-setup}
\end{figure}

Το μετρούμενο μέγεθος είναι ο Σύνθετος Συντελεστής Ανάκλασης Γ, ο οποίος
περιγράφει το πόσο ισχυρά ανακλάται το σήμα σε κάθε συχνότητα και
περιέχει πληροφορία τόσο για το μέγεθος όσο και για τη φάση της
ανάκλασης. Από την κατάλληλη επεξεργασία του συντελεστή ανάκλασης μπορεί
να εξαχθεί πληροφορία σχετικά με τις ηλεκρομαγνητικές ιδιότητες του
υλικού, όπως η σχετική ηλεκτρική διαπερατότητα που όπως αναφέρθηκε
πρόκειται για έναν ισχυρό δείκτη εκτίμησης για την περιεκτικότητα του
νερού \cite{ref23}.

Παρά την υψηλή ακρίβεια που προσφέρουν οι παραπάνω μέθοδοι, τόσο το
κόστος υλοποίησης όσο και η πολυπλοκότητα του συστήματος είναι ιδιαίτερα
αυξημένα. Μία απλουστευμένη και χαμηλότερου κόστους προσέγγιση που
χρησιμοποιείται συχνά βασίζεται στη \textbf{Σύνθετη ή Μιγαδική
Αντίσταση} όπως εφαρμόζεται στα άρθρα \cite{ref24,ref25,ref26,ref27}, μέθοδος που
θα ακολουθηθεί και στην παρούσα εργασία.

Πιο συγκεκριμένα, ένα εναλλασσόμενο σήμα δεδομένης συχνότητας
εφαρμόζεται στο υπό εξέταση δείγμα και μετρώνται η πτώση τάσης και η
διαφορά φάσης μεταξύ τάσης και ρεύματος. Στη συνέχεια, από τις μετρήσεις
αυτές υπολογίζεται η σύνθετη αντίσταση του δείγματος συσχετίζεται με τη
μιγαδική σχετική ηλεκτρική διαπερατότητα του υλικού. Για τη μετάβαση από
το ηλεκτρικό αυτό μέγεθος σε ποσοτική έκφραση της περιεκτικότητας του
δείγματος σε νερό, είναι απαραίτητη η εξαγωγή ενός ηλεκτρικού ισοδύναμου
μοντέλου του δείγματος. Μέσω αυτού, υπολογίζεται η σχετική ηλεκτρική
διαπερατότητα του δείγματος, η οποία εξαρτάται άμεσα από την
περιεκτικότητά του σε νερό. Το θεωρητικό υπόβαθρο της τεχνικής αυτής θα
αναλυθεί στις επόμενες ενότητες.

\begin{figure}[H]
  \centering
  
  \caption{Αναπαράσταση της μέτρησης της μιγαδικής εμπέδησης εδάφους με διάταξη δύο ηλεκτροδίων και εφαρμογή εναλλασσόμενου σήματος.}
  \label{fig:impedance-two-electrode}
\end{figure}

Όπως είναι φανερό, ανεξάρτητα από τη μέθοδο που ακολουθείται, ο τελικός
στόχος αφορά τον υπολογισμό της σχετικής ηλεκτρικής διαπερατότητας του
δείγματος. Τελικά, η παράμετρος αυτή συσχετίζεται με την κατάλληλη
εμπειρική σχέση βαθμονόμησης, με την πλέον διαδεδομένη στη βιβλιογραφία
να αποτελεί η εξίσωση \textbf{Topp}, και περιγράφεται από τη συνάρτηση
\cite{ref02}

\[\theta = - 0.053 + 0.0292K - 5.5 \times 10^{- 4}K^{2} + 4.3 \times 10^{- 6}K^{3}\]

όπου θ η ογκομετρική περιεκτικότητα του εδάφους σε νερό και Κ η
πραγματική συνιστώσα της σχετικής ηλεκτρικής διαπερατότητας.

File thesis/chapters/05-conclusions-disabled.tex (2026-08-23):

\chapter{Συμπεράσματα και Προτάσεις Βελτίωσης}
\label{ch:conclusions}

\section{Προσωρινά συμπεράσματα}
Η ηλεκτρική απόκριση του εδάφους μεταβάλλεται σημαντικά τόσο με τη συχνότητα όσο και με την υγρασία. Στις πολύ χαμηλές συχνότητες κυριαρχεί η πόλωση των ηλεκτροδίων και η ιοντική αγωγιμότητα, ενώ σε υψηλότερες συχνότητες η επίδραση αυτή μειώνεται και αναδεικνύεται περισσότερο η διηλεκτρική συμπεριφορά του νερού.

Τα διαθέσιμα διαγράμματα δείχνουν ότι η αύξηση της υγρασίας μειώνει τις πραγματικές και φανταστικές συνιστώσες της εμπέδησης. Η προσθήκη νερού διευκολύνει την κίνηση διαλυμένων ιόντων και αυξάνει την αγωγιμότητα, με αποτέλεσμα η απόκριση να γίνεται λιγότερο έντονα εξαρτώμενη από τη συχνότητα.

Η αρχική ηλεκτρική μοντελοποίηση υποδεικνύει ότι κανένα απλό ισοδύναμο κύκλωμα δεν περιγράφει κατ' ανάγκη ολόκληρο το εξεταζόμενο φάσμα. Η επιλογή μοντέλου πρέπει να συνδέεται με συγκεκριμένη ζώνη συχνοτήτων και να βασίζεται σε σαφώς ορισμένο κριτήριο προσαρμογής.

\section{Προτάσεις για την ολοκλήρωση της εργασίας}
Για την τελική έκδοση προτείνονται:
\begin{itemize}
  \item πλήρης τεκμηρίωση της προετοιμασίας των δειγμάτων και της γεωμετρίας μέτρησης,
  \item επαναλαμβανόμενες μετρήσεις και παρουσίαση αβεβαιοτήτων,
  \item διαχωρισμός των συχνοτικών περιοχών όπου κυριαρχούν η πόλωση ηλεκτροδίων, η αγωγιμότητα και η διηλεκτρική πόλωση,
  \item προσαρμογή των ισοδύναμων μοντέλων στα πρωτογενή δεδομένα και στατιστική σύγκριση,
  \item βαθμονόμηση της εκτιμώμενης διαπερατότητας ή χωρητικότητας ως προς βαρυμετρική περιεκτικότητα σε νερό και ογκομετρική περιεκτικότητα σε νερό,
  \item επαλήθευση με ανεξάρτητο σύνολο δειγμάτων και, εφόσον είναι δυνατό, με περισσότερους τύπους εδάφους.
\end{itemize}

\section{Επίλογος}
Η φασματοσκοπία εμπέδησης αποτελεί υποσχόμενη προσέγγιση για χαμηλού κόστους εκτίμηση της υγρασίας, αλλά η αξιοπιστία της εξαρτάται από τη βαθμονόμηση, τη συχνότητα λειτουργίας, τη γεωμετρία των ηλεκτροδίων και τις φυσικοχημικές ιδιότητες του εδάφους.

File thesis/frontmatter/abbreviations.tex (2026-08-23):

\chapter*{Συντομογραφίες}
\addcontentsline{toc}{chapter}{Συντομογραφίες}
\begin{longtable}{@{}>{\bfseries}p{0.23\textwidth}p{0.70\textwidth}@{}}
Δ.Ε. & Διπλωματική Εργασία \\
ΔΙ.ΠΑ.Ε. & Διεθνές Πανεπιστήμιο της Ελλάδος \\
\latin{EC} & \latin{Electrical Conductivity} -- Ηλεκτρική αγωγιμότητα \\
\latin{FDR} & \latin{Frequency Domain Reflectometry} \\
\latin{GWC} & \latin{Gravimetric Water Content} -- Βαρυμετρική περιεκτικότητα σε νερό \\
\latin{IS} & \latin{Impedance Spectroscopy} -- Φασματοσκοπία εμπέδησης \\
\latin{MSE} & \latin{Mean Squared Error} -- Μέσο τετραγωνικό σφάλμα \\
\latin{TDR} & \latin{Time Domain Reflectometry} \\
\latin{VNA} & \latin{Vector Network Analyzer} -- Αναλυτής διανυσματικών δικτύων \\
\latin{VWC} & \latin{Volumetric Water Content} -- Ογκομετρική περιεκτικότητα σε νερό
\end{longtable}
\clearpage

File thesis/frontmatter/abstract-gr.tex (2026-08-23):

\chapter*{Περίληψη}
\addcontentsline{toc}{chapter}{Περίληψη}
\vspace*{\fill}
\clearpage

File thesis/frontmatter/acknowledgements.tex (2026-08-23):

\chapter*{Ευχαριστίες}
\addcontentsline{toc}{chapter}{Ευχαριστίες}
\clearpage

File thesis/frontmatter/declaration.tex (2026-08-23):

\thispagestyle{frontmatter}
\begin{center}
\begin{tabularx}{\textwidth}{@{}>{\raggedleft\arraybackslash}p{0.31\textwidth}X@{}}
Τίτλος Διπλωματικής Εργασίας & \thesistitlegr \\
Κωδικός Διπλωματικής Εργασίας & \thesiscode \\
Ονοματεπώνυμο φοιτήτριας & \studentnamegr \\
Ονοματεπώνυμο εισηγητή & \supervisorname \\
Ημερομηνία ανάληψης Διπλωματικής Εργασίας & \assignmentdate \\
Ημερομηνία περάτωσης Διπλωματικής Εργασίας & \completiondate
\end{tabularx}
\end{center}

\vspace{1.25cm}
Βεβαιώνω ότι είμαι ο συγγραφέας αυτής της εργασίας και ότι κάθε βοήθεια την οποία είχα για την προετοιμασία της είναι πλήρως αναγνωρισμένη και αναφέρεται στην εργασία. Επίσης, έχω καταγράψει τις όποιες πηγές από τις οποίες έκανα χρήση δεδομένων, ιδεών, εικόνων και κειμένου, είτε αυτές αναφέρονται ακριβώς είτε παραφρασμένες. Επιπλέον, βεβαιώνω ότι αυτή η εργασία προετοιμάστηκε από εμένα προσωπικά, ειδικά ως διπλωματική εργασία, στο Τμήμα Μηχανικών Πληροφορικής και Ηλεκτρονικών Συστημάτων του Διεθνούς Πανεπιστημίου της Ελλάδος

\vspace{0.8cm}
Η παρούσα εργασία αποτελεί πνευματική ιδιοκτησία της φοιτήτριας \studentnamecover{} που την εκπόνησε. Στο πλαίσιο της πολιτικής ανοικτής πρόσβασης, ο/η συγγραφέας/δημιουργός εκχωρεί στο Διεθνές Πανεπιστήμιο της Ελλάδος άδεια χρήσης του δικαιώματος αναπαραγωγής, δανεισμού, παρουσίασης στο κοινό και ψηφιακής διάχυσης της εργασίας διεθνώς, σε ηλεκτρονική μορφή και σε οποιοδήποτε μέσο, για διδακτικούς και ερευνητικούς σκοπούς, άνευ ανταλλάγματος. Η ανοικτή πρόσβαση στο πλήρες κείμενο της εργασίας δεν σημαίνει καθ' οιονδήποτε τρόπο παραχώρηση δικαιωμάτων διανοητικής ιδιοκτησίας του/της συγγραφέα/δημιουργού, ούτε επιτρέπει την αναπαραγωγή, αναδημοσίευση, αντιγραφή, πώληση, εμπορική χρήση, διανομή, έκδοση, μεταφόρτωση, ανάρτηση, μετάφραση ή τροποποίηση χωρίς τη ρητή προηγούμενη έγγραφη συναίνεσή του/της.

\vspace{0.8cm}
Η έγκριση της διπλωματικής εργασίας από το Τμήμα Μηχανικών Πληροφορικής και Ηλεκτρονικών Συστημάτων του Διεθνούς Πανεπιστημίου της Ελλάδος δεν υποδηλώνει απαραιτήτως και αποδοχή των απόψεων του/της συγγραφέα εκ μέρους του Τμήματος.
\clearpage

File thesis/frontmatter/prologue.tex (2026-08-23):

\chapter*{Πρόλογος}
\addcontentsline{toc}{chapter}{Πρόλογος}
\clearpage

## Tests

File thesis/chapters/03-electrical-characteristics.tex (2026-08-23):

\chapter{Ηλεκτρικά Χαρακτηριστικά Εδάφους}
\label{ch:electrical}

\section{Εισαγωγή}

Στο παρόν κεφάλαιο παρουσιάζεται η πειραματική διαδικασία που
ακολουθήθηκε για τον ηλεκτρικό χαρακτηρισμό των δειγμάτων εδάφους μέσω
Φασματοσκοπίας Εμπέδησης (Electrochemical Impedance Spectroscopy, EIS).
Αρχικά περιγράφονται οι βασικές αρχές της τεχνικής και η χρησιμότητά της
για τον χαρακτηρισμό του συστήματος. Στη συνέχεια, παρουσιάζεται η
μεθοδολογία που εφαρμόστηκε καθώς και τα συμπεράσματα για το ηλεκτρικό
ισοδύναμο του δείγματος εδάφους που εξετάστηκε.

\section{Φασματοσκοπία Εμπέδησης}

Η Φασματοσκοπία Εμπέδησης είναι μία τεχνική που εφαρμόζει ένα
ημιτονοειδές εναλλασσόμενο ηλεκτρικό σήμα μικρού πλάτους σε ένα υπό
εξέταση σύστημα και μετρά την απόκρισή του σε ένα φάσμα συχνοτήτων. Όταν
το δείγμα διεγείρεται, για κάθε διαφορετικό εύρος συχνοτήτων κυριαρχούν
και οι αντίστοιχοι μηχανισμοί. Η απόκριση του συστήματος εκφράζεται μέσω
της σύνθετης αντίστασης και μπορεί να περιγράψει τους μηχανισμούς αυτούς
μοντελοποιώντας το σύστημα με ένα αντίστοιχο ηλεκτρικό κυκλωματικό
ισοδύναμο. \cite{ref22}

\section{Εξοπλισμός και Μέθοδος}

Για τη μελέτη της απόκρισης των δειγμάτων συναρτήσει της συχνότητας
χρησιμοποιήθηκε ο Αναλυτής Σύνθετης Εμπέδησης (Impedance Analyzer) της
Keysight Technologies E4990A. Το εύρος συχνοτήτων που αξιολογήθηκαν
είναι από 20Hz έως 1.5MHz, συχνότητες που θεωρήθηκαν ασφαλείς μετά τη
δοκιμή γνωστών στοιχείων. Με στόχο τη μέγιστη ακρίβεια, η βαθμονόμιση
του οργάνου και οι μετρήσεις έγιναν τμηματικά στο φάσμα της συχνότητας,
προκειμένου να ελαχιστοποιηθούν τα συχνοεξαρτώμενα σφάλματα του αναλυτή
και των καλωδίω, και με στόχο να αυξηθεί ο αριθμός των συνολικών
δειγμάτων. Η τάση που εφαρμόζει ο αναλυτής είναι 500mVrms, τάση που
οφείλει να είναι χαμηλή ώστε να μην υπερφορτώνεται το δείγμα. Ο τύπος
του δείγματος που χρησιμοποιήθηκε εντάσσεται στην κατηγορία Sandy Loam.
\cite{ref31}

\section{Απόκριση Συστήματος}

Η απόκριση του συστήματος για (f)=20Hz-1.5MHz και gwc 10\% φαίνεται στο
\figref{fig:impedance-magnitude}. Είναι χαρακτηριστική η μεγάλη τιμή του μέτρου της εμπέδησης (
\textbar Ζ\textbar{} ) στις πολύ χαμηλές συχνότητες, γεγονός που μπορεί
να δικαιολογηθεί από την πόλωση των ηλεκτροδίων. Από τα 10kHz και μετά,
παρατηρείται σταδιακή μείωση του \textbar Z\textbar. Ωστόσο, στις
υψηλότερες συχνότητες το \textbar Z\textbar{} τείνει να σταθεροποιηθεί,
γεγονός που υποδηλώνει ότι στην περιοχή αυτή το \textbar Z\textbar{}
επηρεάζεται λιγότερο από την εφαρμοζόμενη συχνότητα.

Η πόλωση των ηλεκτροδίων είναι ένα φαινόμενο που εμφανίζεται μεταξύ
ηλεκτροδίου-μέσου όταν εφαρμόζεται ηλεκτρομαγνητικό πεδίο και δεν
υπάρχει πραγματική μεταφορά φορτίου. Τα φορτία συσσωρεύονται αλλά δεν
περνούν στο μέσο, σχηματίζοντας τη λεγόμενη Ηλεκτρική Διπλοστιβάδα
(Electrical Double Layer) η οποία προκαλεί τη μεγάλη τιμή του
\textbar Z\textbar{} στις χαμηλές συχνότητες (\figref{fig:electrode-polarization}).

\begin{figure}[H]
  \centering
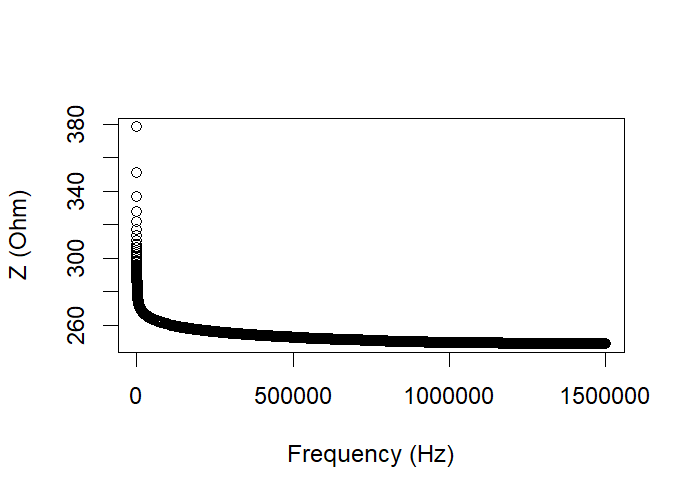
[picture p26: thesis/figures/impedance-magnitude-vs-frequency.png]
  
  \caption{Συχνοτική απόκριση δείγματος με gwc 10\% από 20Hz έως 1,5MHz.}
  \label{fig:impedance-magnitude}
\end{figure}

\begin{figure}[H]
  \centering
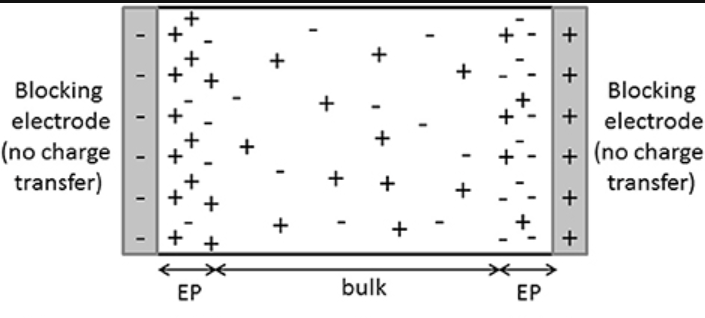
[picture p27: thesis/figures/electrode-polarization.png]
  
  \caption{Το φαινόμενο της Ηλεκτρικής Διπλοστιβάδας μεταξύ ηλεκτροδίου και μέσου. \cite{ref30}}
  \label{fig:electrode-polarization}
\end{figure}

Στο \figref{fig:phase-frequency} φαίνεται το διάγραμμα της φάσης συναρτήσει της συχνότητας.
Στις χαμηλές συχνότητες εμφανίζεται ξανά η πόλωση των ηλεκτροδίων, ενώ
παραλείποντας αυτό το εύρος, η φάση βρίσκεται πολύ κοντά στο μηδέν και
με σταδιακή αύξηση της συχνότητας γίνεται αρνητικότερη.

\begin{figure}[H]
  \centering
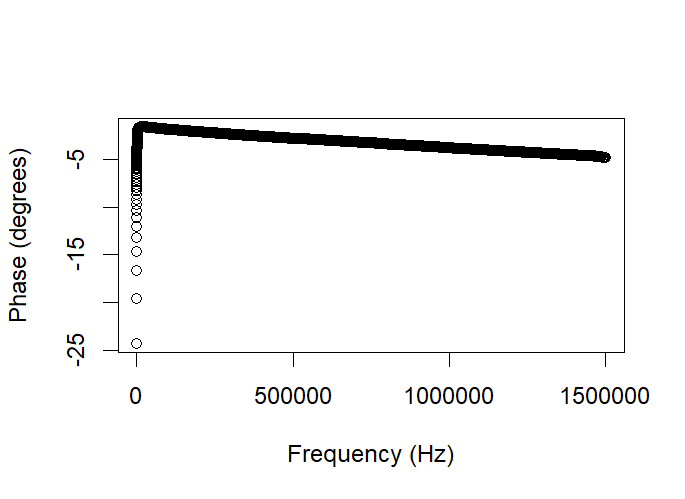
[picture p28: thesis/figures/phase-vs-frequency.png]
  
  \caption{Διάγραμμα φάσης-Συχνότητας για δείγμα με gwc 10\% από 20Hz έως 1,5MHz.}
  \label{fig:phase-frequency}
\end{figure}

Ένα χρήσιμο εργαλείο που χρησιμοποιείται συχνά στην Φασματοσκοπία
Εμπέδησης είναι το διάγραμμα Nyquist που φαίνεται στο \figref{fig:nyquist-full}. Η
συχνότητα αυξάνεται από τα δεξιά προς τα αριστερά, στον Χ-άξονα
απεικονίζεται η πραγματική συνιστώσα Z' που εκφράζει την ωμική
συμπεριφορά του συστήματος και στον Υ-άξονα η φανταστική συνιστώσα
-Ζ'\,' που εκφράζει είτε τη χωρητική είτε την επαγωγική συμπεριφορά,
όπου

\[Z' = |Z|\cos t\quad\text{και}\quad Z'' = |Z|\sin t\]

\begin{figure}[H]
  \centering
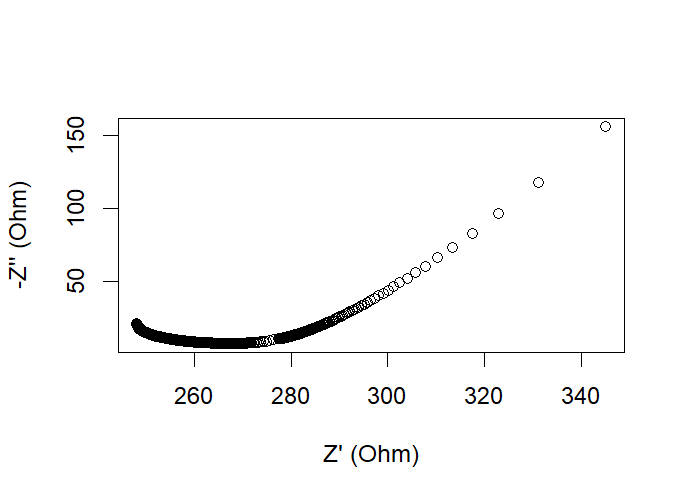
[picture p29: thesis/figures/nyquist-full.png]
  
  \caption{Διάγραμμα Nyquist για δείγμα με gwc 10\% από 20Hz έως 1,5MHz.}
  \label{fig:nyquist-full}
\end{figure}

Η επίδραση των ηλεκτροδίων στα διαγράμματα Nyquist εμφανίζεται ως μια
χαρακτηριστική ουρά 45 μοιρών στις χαμηλές συχνότητες (δεξιά), γεγονός
που επιβεβαιώνεται και στο δείγμα όπως φαίνεται στο \figref{fig:nyquist-full}. Στις
μεσαίες συχνότητες, το φανταστικό μέρος παραμένει σχεδόν σταθερό ενώ το
πραγματικό μειώνεται. Στις υψηλότερες συχνότητες και συγκεκριμένα γύρω
από τη συχνότητα 1MHz και υψηλότερα, παρατηρείται μία απότομη ανοδική
αύξηση στο Z'\,' με σχετική σταθεροποίηση του Ζ'. Αυτό μπορεί να
δικαιολογηθεί από την μετάβαση της ιοντικής αγωγιμότητας που πλέον δε
δύναται να ακολουθήσει το πεδίο, στην επικράτηση της διηλεκτρικής
πόλωσης των μορίων, και κυρίως των διπόλων του νερού, που έχουν υψηλή
διηλετρική σταθερά. Στο \figref{fig:nyquist-trimmed} φαίνεται ευκρινέστερα η απόκριση του
δείγματος μετά την αφαίρεση των συχνοτήτων όπου κυριαρχεί η πόλωση των
ηλεκτροδίων.

Στο \figref{fig:nyquist-moisture} φαίνεται το διάγραμμα Nyquist για τρία ποσοστά υγρασίας
στο ίδιο δείγμα, με gwc 7\%, 10\% και 16\% αντίστοιχα.

\begin{figure}[H]
  \centering
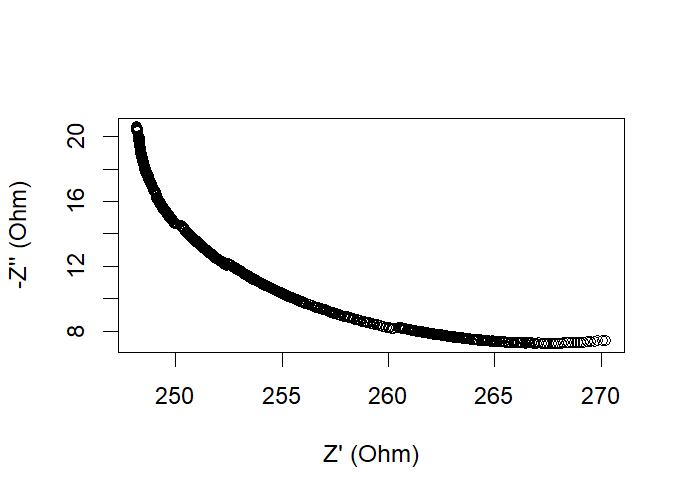
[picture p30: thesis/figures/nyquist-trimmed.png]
  
  \caption{Διάγραμμα Nyquist για δείγμα με gwc 10\% εξαιρώντας τα πολωτικά φαινόμενα.}
  \label{fig:nyquist-trimmed}
\end{figure}

\begin{figure}[H]
  \centering
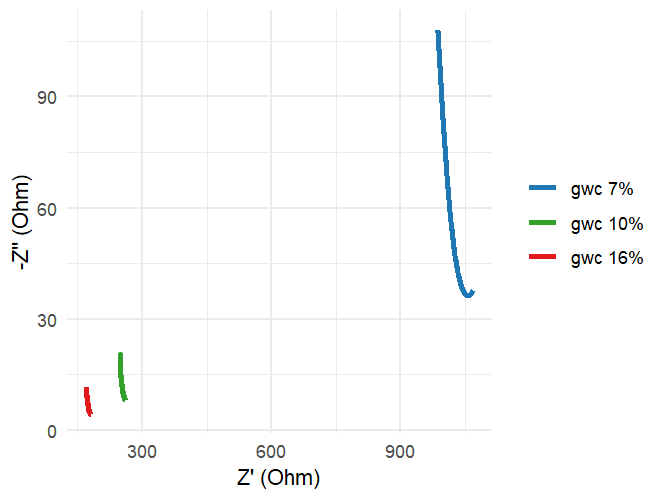
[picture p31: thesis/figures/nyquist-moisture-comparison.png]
  
  \caption{Διάγραμμα Nyquist για δείγματα με gwc 7\%, 10\% και 16\%.}
  \label{fig:nyquist-moisture}
\end{figure}

Είναι φανερή η επίδραση της υγρασίας στην απόκριση του συστήματος, αφού
τόσο η πραγματική όσο και η φανταστική συνιστώσα μειώνονται με την
προσθήκη νερού. Για χαμηλά ποσοστά υγρασίας η απόκριση είναι έντονα
εξαρτώμενη από τη συχνότητα, καθώς επηρεάζεται από τη χωρητική
συμπεριφορά του δείγματος. Με την προσθήκη νερού, αυξάνονται τα
διαλυμένα ιόντα και διευκολύνεται η κινητικότητά τους με αποτέλεσμα να
αυξάνεται σημαντικά η αγωγιμότητα. Ως επακόλουθο, η συχνότητα επηρεάζει
σημαντικά λιγότερο την απόκριση.

\section{Ηλεκτρική Μοντελοποίηση του Εδάφους}

Για την καλύτερη κατανόηση των ιδιοτήτων και της συμπεριφοράς ενός μέσου
είναι αναγκαία η μοντελοποίηση του με ένα αντίστοιχο ηλεκτρικό
κυκλωματικό ισοδύναμο. Η συμπεριφορά του εδάφους ωστόσο δεν είναι
απόλυτη, καθώς εξαρτάται από το είδος και το μέγεθος των κόκκων, το
ποσοστό υγρασίας, αλλά και τη συχνότητα στην οποία το εξετάζουμε. Έτσι,
στη βιβλιογραφία αναφέρεται μία πληθώρα κυκλωμάτων ανάλογα με την
εκάστοτε περίπτωση. Έχουν επιλεχθεί να εξεταστούν δύο από τα πιο βασικά
μοντέλα, τα οποία φαίνονται στο \figref{fig:equivalent-model-1} και στο \figref{fig:equivalent-model-2}.

\begin{figure}[H]
  \centering
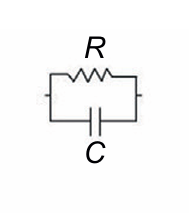
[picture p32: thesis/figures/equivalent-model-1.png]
  
  \caption{Ηλεκτρικό κυκλωματικό ισοδύναμο εδάφους για το μοντέλο 1: παράλληλος συνδυασμός RC.}
  \label{fig:equivalent-model-1}
\end{figure}

\begin{figure}[H]
  \centering
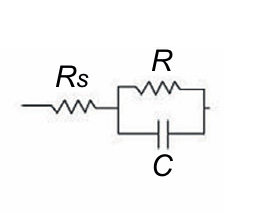
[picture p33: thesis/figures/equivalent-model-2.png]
  
  \caption{Ηλεκτρικό κυκλωματικό ισοδύναμο εδάφους για το μοντέλο 2: αντίσταση Rs σε σειρά με παράλληλο συνδυασμό RC.}
  \label{fig:equivalent-model-2}
\end{figure}

Επειδή, όπως αναφέρθηκε, το ισοδύναμο μοντέλο δύναται να αλλάζει ανάλογα
με τη συχνότητα, η σύγκριση έγινε στις εξής δύο περιοχές:

α) Στη χαμηλή ζώνη (100kHz-200kHz) συχνοτήτων όπου μελετάται συνήθως η
αγώγιμη συμπεριφορά, παρακάμπτοντας τα πολωτικά φαινόμενα των
ηλεκτροδίων

β) Στην υψηλή ζώνη (1MHz-1,3MHz) συχνοτήτων όπου μελετάται συνήθως η
χωρητική συμπεριφορά

Για την αξιολόγηση της ακρίβειας των θεωρητικών μοντέλων συγκριτικά με
τα πραγματικά δεδομένα έχει υπολογιστεί το Μέσο Τετραγωνικό Σφάλμα του
κάθε μοντέλου στις δύο παραπάνω περιοχές για μία μέση τιμή υγρασίας
(s10\%) (\tabref{tab:model-mse}).

\begin{table}[H]
  \centering
  \begin{tabularx}{\textwidth}{>{\centering\arraybackslash}X *{4}{>{\centering\arraybackslash}X}}
    \toprule
      & \multicolumn{2}{c}{Z MSE} & \multicolumn{2}{c}{Z Phase} \\
    \cmidrule(lr){2-3}\cmidrule(lr){4-5}
    \textbf{Ζώνη συχνοτήτων} & \textbf{Μοντέλο 1} & \textbf{Μοντέλο 2} & \textbf{Μοντέλο 1} & \textbf{Μοντέλο 2} \\
    \midrule
    Χαμηλή ζώνη συχνοτήτων & 2,27 & 0,72 & 0,0033 & 0,02 \\
    Υψηλή ζώνη συχνοτήτων & 0,048 & 0,18 & 0,00012 & 0,00017 \\
    \bottomrule
  \end{tabularx}
  \caption{Μέσω Τετραγωνικό Σφάλμα για το μέτρο της σύνθετης αντίστασης και της φάσης για δείγμα με gwc 10\% στις δύο περιοχές συχνοτήτων}
  \label{tab:model-mse}
\end{table}

Παρατηρείται πως στις χαμηλότερες συχνότητες το μοντέλο 2 προσομοιώνει
καλύτερα τη συμπεριφορά του δείγματος όσον αφορά το μέτρο της σύνθετης
αντίστασης, ενώ για τη φάση παρά τη μικρή τιμή του μέσου τετραγωνικού
σφάλματος ισχύει το αντίστροφο. Στις υψηλότερες συχνότητες το μοντέλο 1
είναι το βέλτιστο για τη προσομοίωση του μέτρου της σύνθετης αντίστασης,
ενώ η διαφορά των δύο σφαλμάτων για τη φάση είναι εξαιρετικά μικρή.

Επομένως, το δείγμα δεν έχει μία δεδομένη συμπεριφορά, αλλά μπορεί να
μεταβάλλεται στο φάσμα της συχνότητας. Για την αξιοποίηση ενός μοντέλου
είναι απαραίτητη η αξιολόγησή του σε ένα στενό φάσμα κοντά στη συχνότητα
που θα εξεταστεί.

Παρακάτω φαίνεται η έντονη πόλωση των ηλεκτροδίων από τον αναλυτή στην
περιοχή 20Hz-1kHz, καθώς και η απόκριση του δείγματος συγκριτικά με τα
θεωρητικά μοντέλα στις δύο περιοχές συχνοτήτων.

\begin{figure}[H]
  \centering
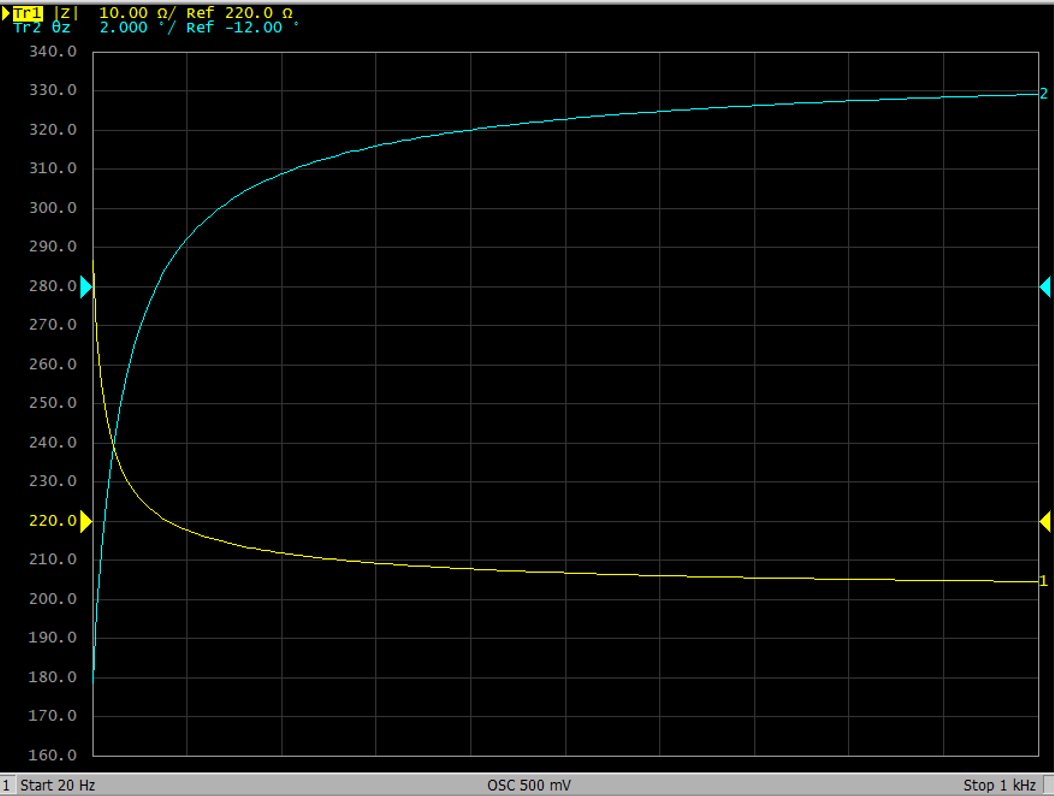
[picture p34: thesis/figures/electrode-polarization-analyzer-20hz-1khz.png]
  
  \caption{Η απόκριση του μέτρου της εμπέδησης και της φάσης σε χαμηλές συχνότητες από 20Hz έως 1kHz με εμφανή την πόλωση των ηλεκτροδίων.}
  \label{fig:electrode-polarization-analyzer}
\end{figure}

\clearpage
\begin{figure}[H]
  \centering
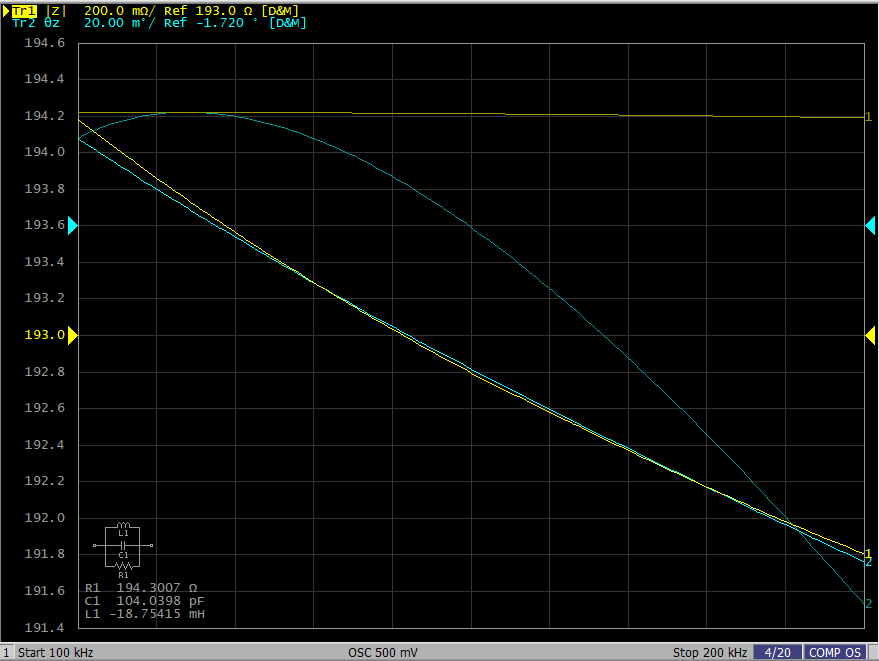
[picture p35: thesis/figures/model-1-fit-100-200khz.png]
  
  \caption{Πραγματική και θεωρητική μεταβολή του μέτρου της εμπέδησης και της φάσης για το μοντέλο 1 από 100kHz έως 200kHz.}
  \label{fig:model1-low-fit}
\end{figure}

\begin{figure}[H]
  \centering
  
  \caption{Πραγματική και θεωρητική μεταβολή του μέτρου της εμπέδησης και της φάσης για το μοντέλο 2 από 100kHz έως 200kHz.}
  \label{fig:model2-low-fit}
\end{figure}

\clearpage
\begin{figure}[H]
  \centering
  
  \caption{Πραγματική και θεωρητική μεταβολή του μέτρου της εμπέδησης και της φάσης για το μοντέλο 1 από 1MHz έως 1.5MHz.}
  \label{fig:model1-high-fit}
\end{figure}

\begin{figure}[H]
  \centering
  
  \caption{Πραγματική και θεωρητική μεταβολή του μέτρου της εμπέδησης και της φάσης για το μοντέλο 2 από 1MHz έως 1.5MHz.}
  \label{fig:model2-high-fit}
\end{figure}

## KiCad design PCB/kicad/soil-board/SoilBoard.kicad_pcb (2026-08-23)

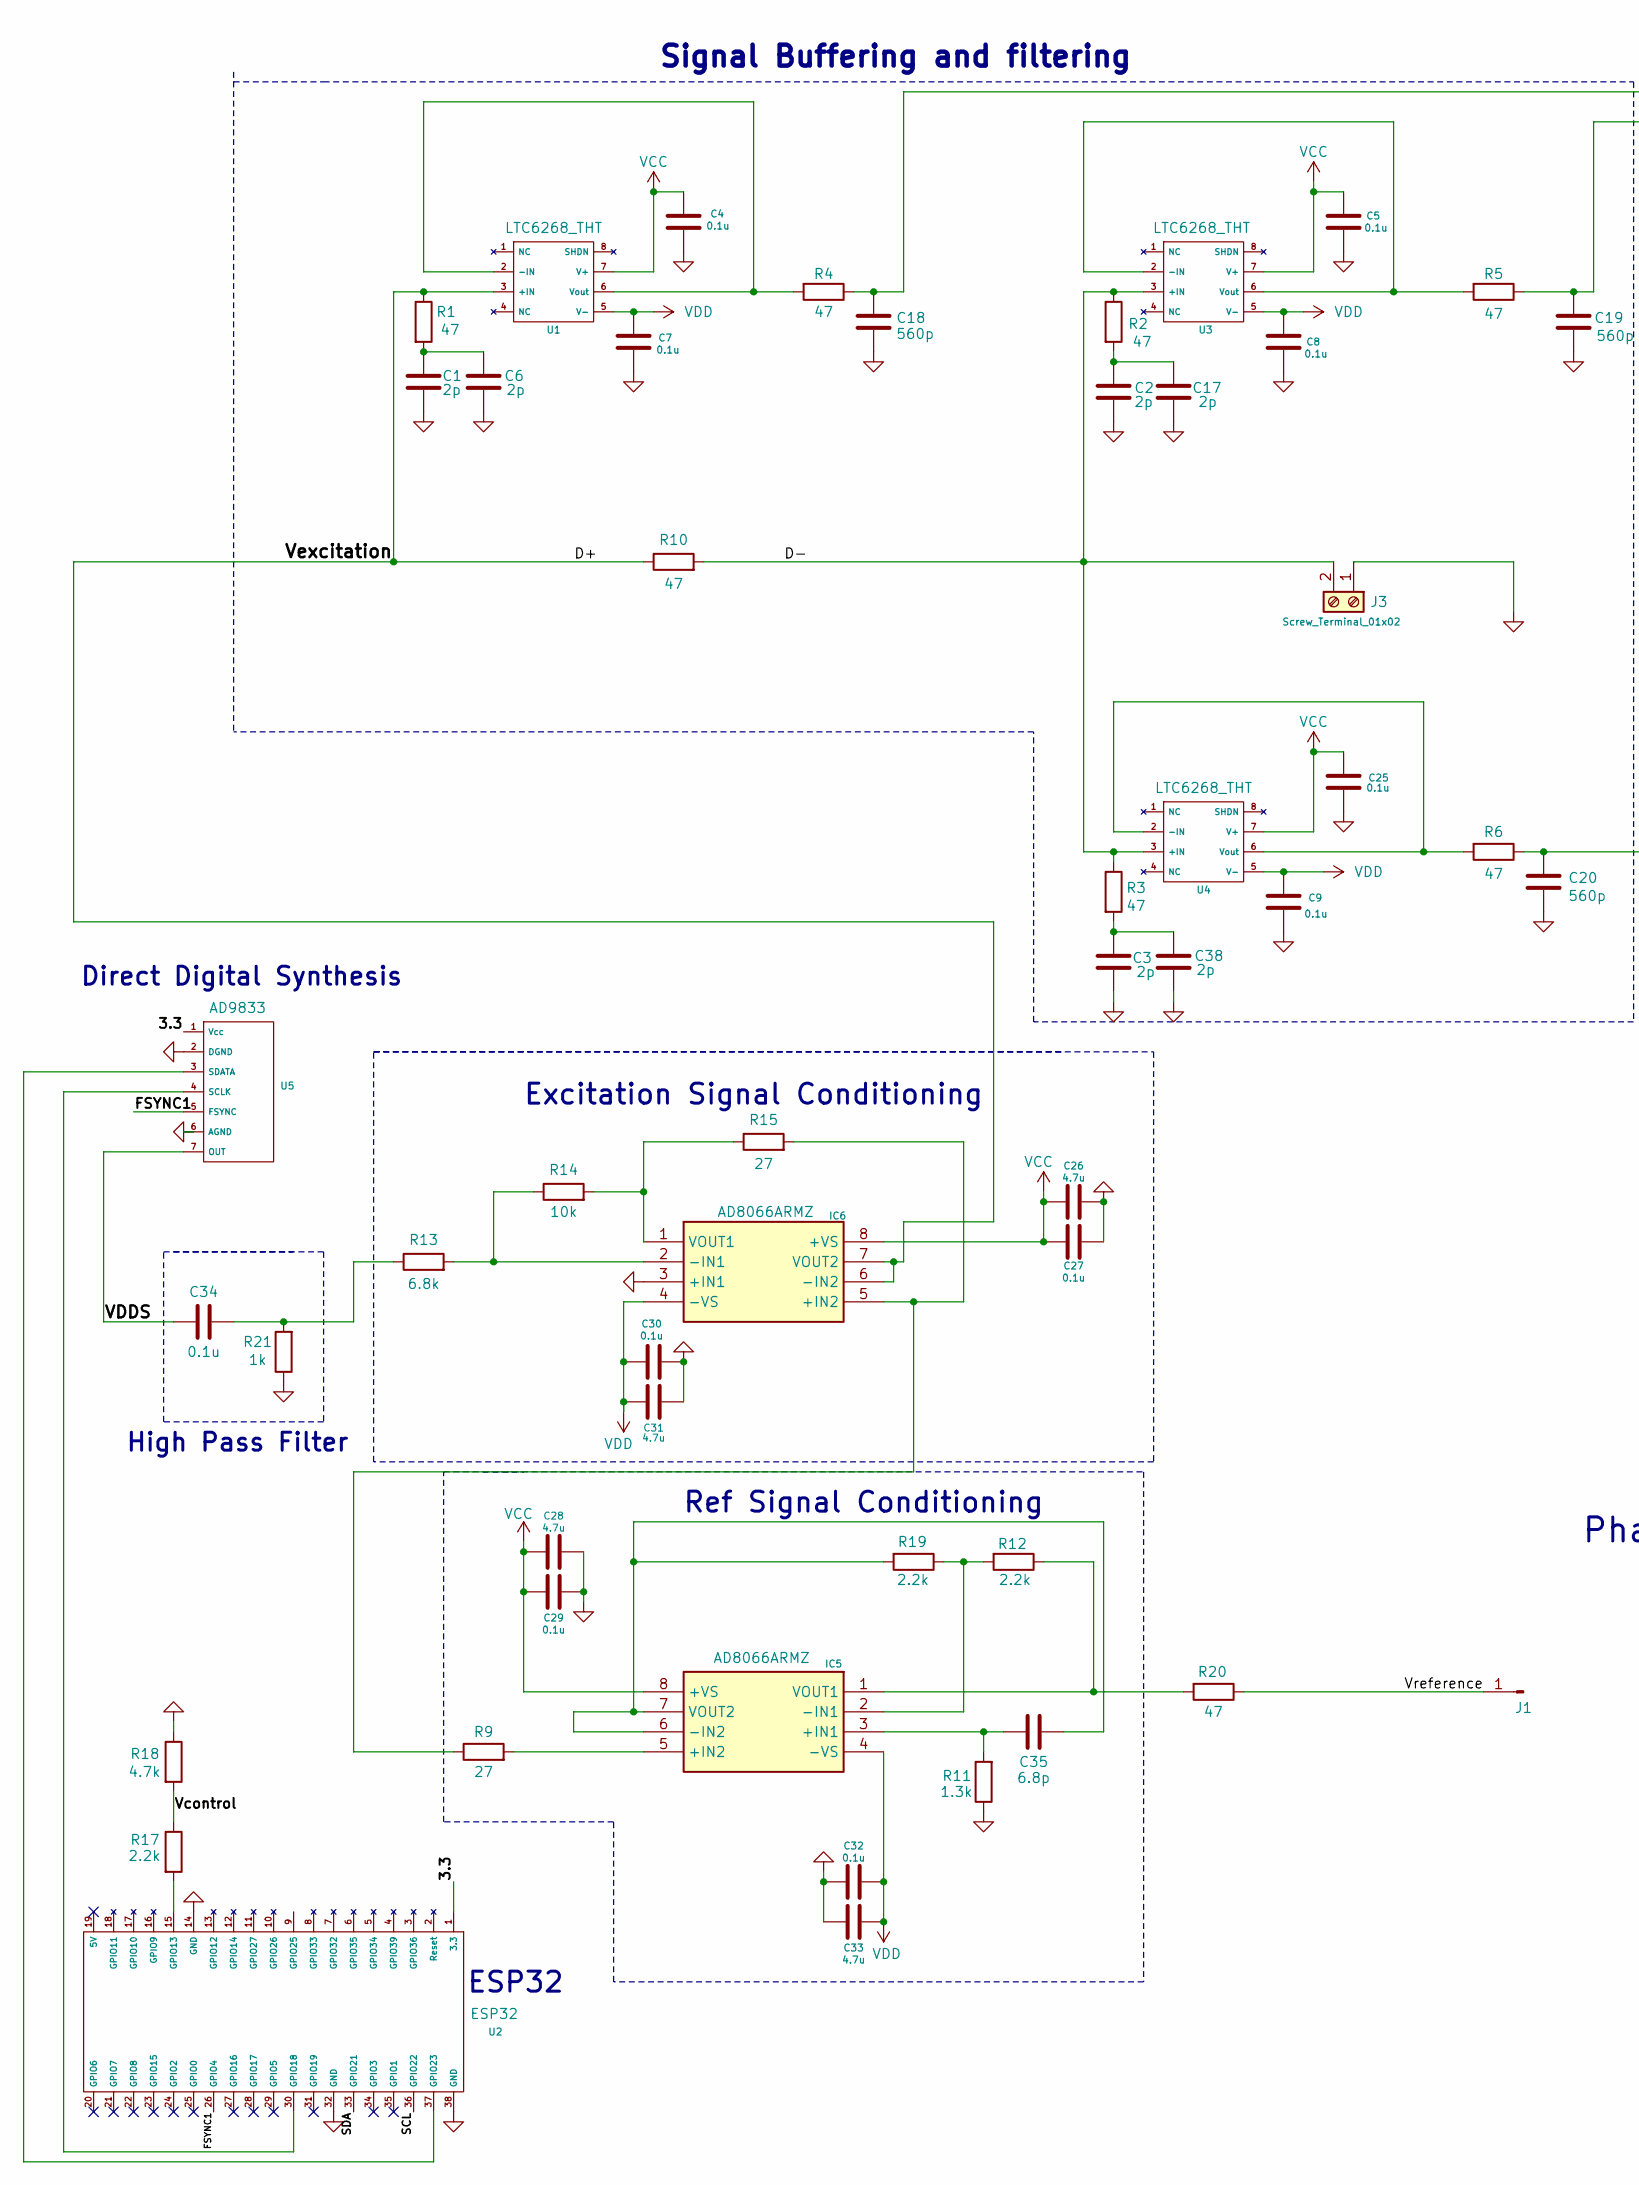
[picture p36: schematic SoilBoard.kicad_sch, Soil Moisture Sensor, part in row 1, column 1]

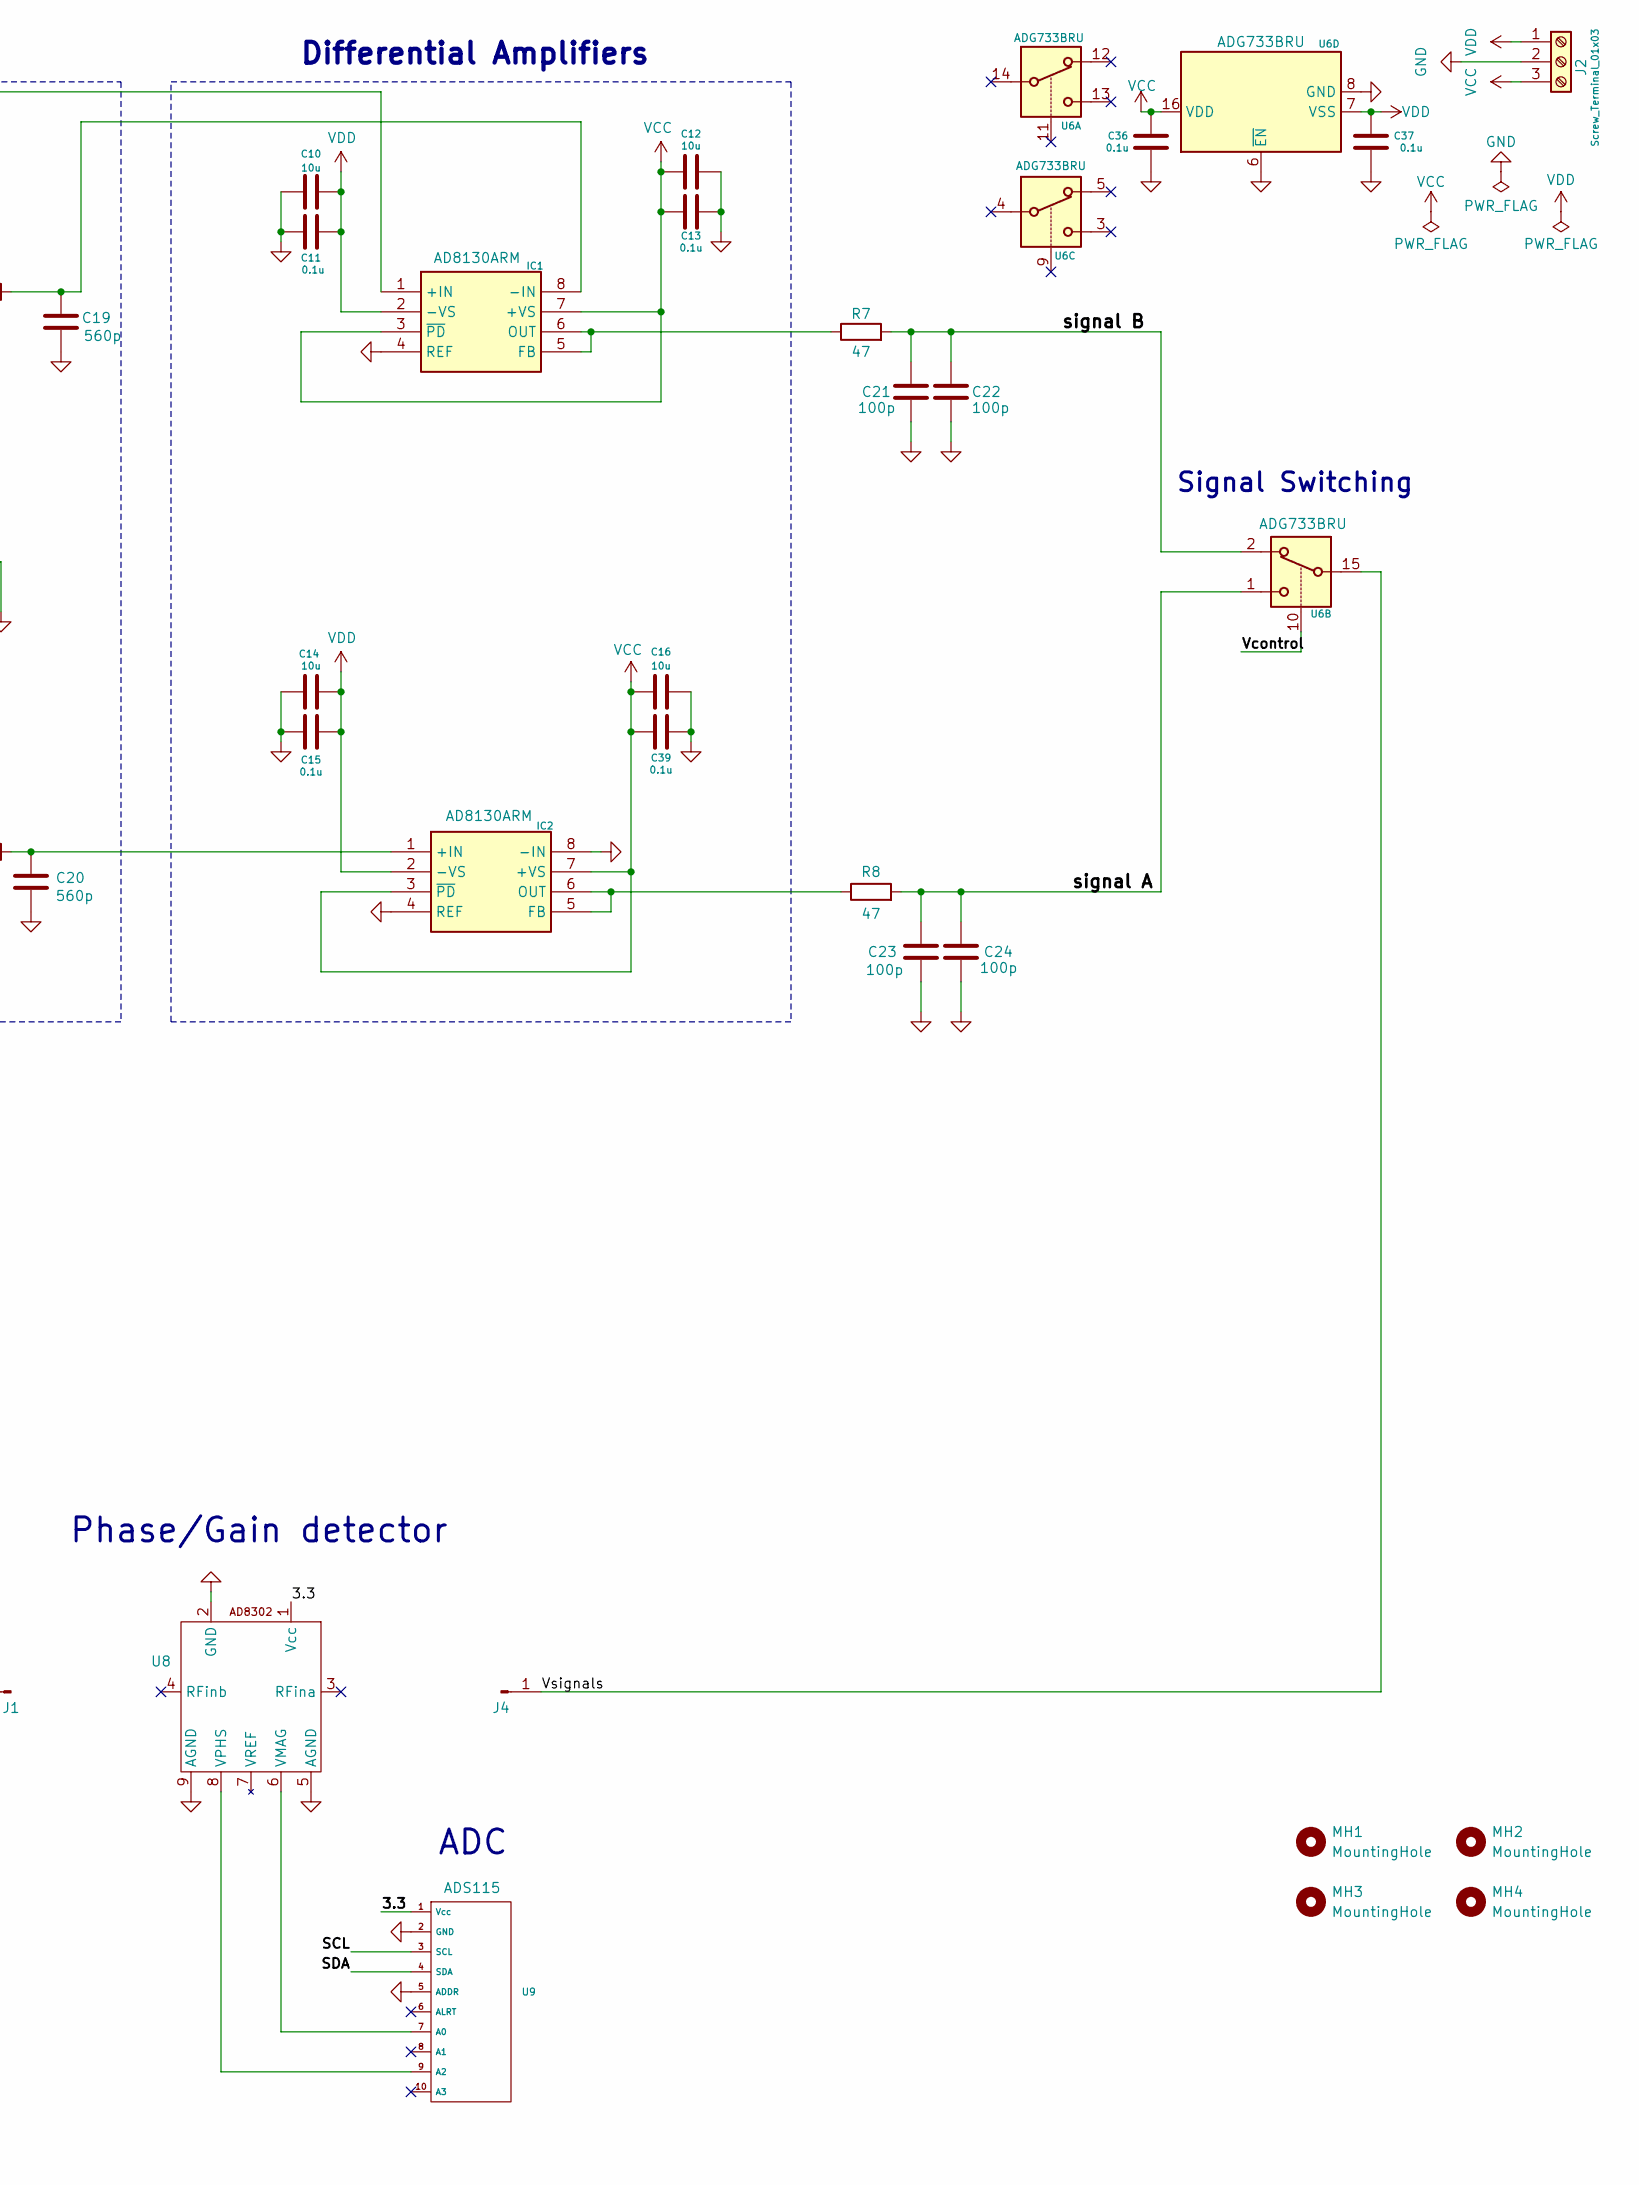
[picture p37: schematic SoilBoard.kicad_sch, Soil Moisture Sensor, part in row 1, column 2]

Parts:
C1, C2, C3, C6, C17, C38: 2p; C_Axial_L3.8mm_D2.6mm_P10.00mm_Horizontal
C4, C5, C7, C8, C9, C11, C13, C15, C25, C27, C29, C30, C32, C34, C36, C37, C39: 0.1u; C_Disc_D5.0mm_W2.5mm_P5.00mm
C10, C12, C14, C16: 10u; CP_Radial_D5.0mm_P2.50mm
C18, C19, C20: 560p; C_Disc_D5.0mm_W2.5mm_P5.00mm
C21, C22, C23, C24: 100p; C_Disc_D5.0mm_W2.5mm_P2.50mm
C26, C28, C31, C33: 4.7u; CP_Radial_D5.0mm_P2.50mm
C35: 6.8p; C_Disc_D5.0mm_W2.5mm_P5.00mm
IC1, IC2: AD8130ARM; PowerIntegrations_SO-8; Manufacturer_Part_Number AD8130ARM; Mouser Part Number 584-AD8130ARM
IC5, IC6: AD8066ARMZ; PowerIntegrations_SO-8; Manufacturer_Part_Number AD8066ARMZ; Mouser Part Number 584-AD8066ARMZ
J1, J4: Conn_01x01_Pin; U.FL_Molex_MCRF_73412-0110_Vertical
J2: Screw_Terminal_01x03; TerminalBlock_MaiXu_MX126-5.0-03P_1x03_P5.00mm
J3: Screw_Terminal_01x02; TerminalBlock_MaiXu_MX126-5.0-02P_1x02_P5.00mm
MH1, MH2, MH3, MH4: MountingHole; MountingHole_2.1mm
R1, R2, R3, R4, R5, R6, R7, R8, R10, R20: 47; R_Axial_DIN0207_L6.3mm_D2.5mm_P10.16mm_Horizontal
R9, R15: 27; R_Axial_DIN0207_L6.3mm_D2.5mm_P10.16mm_Horizontal
R11: 1.3k; R_Axial_DIN0207_L6.3mm_D2.5mm_P10.16mm_Horizontal
R12, R17, R19: 2.2k; R_Axial_DIN0207_L6.3mm_D2.5mm_P10.16mm_Horizontal
R13: 6.8k; R_Axial_DIN0207_L6.3mm_D2.5mm_P10.16mm_Horizontal
R14: 10k; R_Axial_DIN0207_L6.3mm_D2.5mm_P10.16mm_Horizontal
R18: 4.7k; R_Axial_DIN0207_L6.3mm_D2.5mm_P10.16mm_Horizontal
R21: 1k; R_Axial_DIN0207_L6.3mm_D2.5mm_P10.16mm_Horizontal
U1, U3, U4: LTC6268_THT; PowerIntegrations_SO-8
U2: ESP32
U5: AD9833
U6: ADG733BRU; TSSOP-16_4.4x5mm_P0.65mm
U8: AD8302
U9: ADS115; ADS1115

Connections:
/3.3: U2.1 (3.3), U5.1 (Vcc), U8.1 (Vcc), U9.1 (Vcc)
/D+: IC6.6 (-IN2), IC6.7 (VOUT2), R1.1, R10.1, U1.3 (+IN)
/D-: J3.2, R2.1, R3.1, R10.2, U3.3 (+IN), U4.3 (+IN)
/FSYNC1: U2.26 (GPIO4), U5.5 (FSYNC)
/SCL: U2.36 (GPIO22), U9.3 (SCL)
/SDA: U2.33 (GPIO21), U9.4 (SDA)
/VDDS: C34.2, U5.7 (OUT)
/Vcontrol: R17.1, R18.2, U6.10
/Vreference: J1.1 (Pin_1_1), R20.1
/Vsignals: J4.1 (Pin_1_1), U6.15
/signal A: C23.1, C24.1, R8.2, U6.1
/signal B: C21.1, C22.1, R7.2, U6.2
GND: C1.2, C2.2, C3.2, C4.2, C5.2, C6.2, C7.2, C8.2, C9.2, C10.1, C11.1, C12.2, C13.2, C14.1, C15.1, C16.2, C17.2, C18.2, C19.2, C20.2, C21.2, C22.2, C23.2, C24.2, C25.2, C26.2, C27.2, C28.2, C29.2, C30.2, C31.2, C32.2, C33.2, C36.2, C37.2, C38.2, C39.2, IC1.4 (REF), IC2.4 (REF), IC2.8 (-IN), IC6.3 (+IN1), J1.2, J2.2, J3.1, J4.2, R11.1, R18.1, R21.1, U2.14 (GND), U2.32 (GND), U2.38 (GND), U5.2 (DGND), U5.6 (AGND), U6.6 (~EN), U6.8 (GND), U8.2 (GND), U8.5 (AGND), U8.9 (AGND), U9.2 (GND), U9.5 (ADDR)
unnamed: C1.1, C6.1, R1.2
unnamed: C3.1, C38.1, R3.2
unnamed: C2.1, C17.1, R2.2
unnamed: C34.1, R13.1, R21.2
unnamed: C18.1, IC1.1 (+IN), R4.1
unnamed: C19.1, IC1.8 (-IN), R5.1
unnamed: IC1.5 (FB), IC1.6 (OUT), R7.1
unnamed: C20.1, IC2.1 (+IN), R6.1
unnamed: IC2.5 (FB), IC2.6 (OUT), R8.1
unnamed: C35.1, IC5.3 (+IN1), R11.2
unnamed: IC5.5 (+IN2), R9.2
unnamed: IC5.2 (-IN1), R12.2, R19.1
unnamed: C35.2, IC5.6 (-IN2), IC5.7 (VOUT2), R19.2
unnamed: IC5.1 (VOUT1), R12.1, R20.2
unnamed: IC6.5 (+IN2), R9.1, R15.2
unnamed: IC6.2 (-IN1), R13.2, R14.1
unnamed: IC6.1 (VOUT1), R14.2, R15.1
unnamed: R4.2, U1.2 (-IN), U1.6 (Vout)
unnamed: R17.2, U2.15 (GPIO13)
unnamed: U2.30 (GPIO18), U5.4 (SCLK)
unnamed: U2.37 (GPIO23), U5.3 (SDATA)
unnamed: R5.2, U3.2 (-IN), U3.6 (Vout)
unnamed: R6.2, U4.2 (-IN), U4.6 (Vout)
unnamed: U8.6 (VMAG), U9.7 (A0)
unnamed: U8.8 (VPHS), U9.9 (A2)
VCC: C4.1, C5.1, C12.1, C13.1, C16.1, C25.1, C26.1, C27.1, C28.1, C29.1, C36.1, C39.1, IC1.3 (~PD), IC1.7 (+VS), IC2.3 (~PD), IC2.7 (+VS), IC5.8 (+VS), IC6.8 (+VS), J2.3, U1.7 (V+), U3.7 (V+), U4.7 (V+), U6.16 (VDD)
VDD: C7.1, C8.1, C9.1, C10.2, C11.2, C14.2, C15.2, C30.1, C31.1, C32.1, C33.1, C37.1, IC1.2 (-VS), IC2.2 (-VS), IC5.4 (-VS), IC6.4 (-VS), J2.1, U1.5 (V-), U3.5 (V-), U4.5 (V-), U6.7 (VSS)

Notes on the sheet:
Excitation Signal Conditioning
ADC
ESP32
Phase/Gain detector
Differential Amplifiers
Signal Switching
Ref Signal Conditioning
Signal Buffering and filtering
Direct Digital Synthesis
High Pass Filter

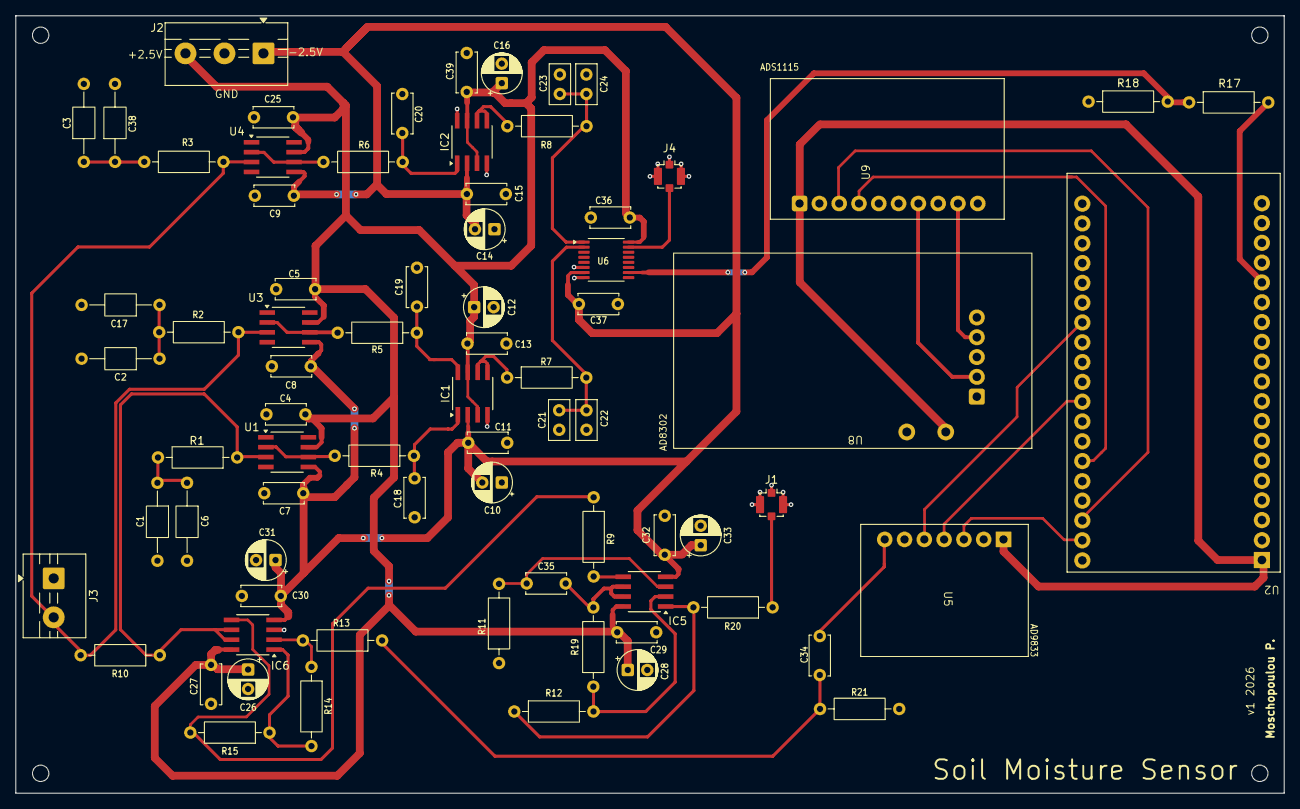
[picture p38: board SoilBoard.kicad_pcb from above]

Board: 2 copper layers, 162.7 x 99.7 mm, 79 parts (0 on the bottom side), 40 nets.

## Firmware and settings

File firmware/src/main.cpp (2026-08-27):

#include <Arduino.h>
#include <SPI.h>
#include <WiFi.h>
#include <WiFiManager.h>
#include <Preferences.h>

#include "AD9833.h"
#include <Adafruit_ADS1X15.h>
#include "thingProperties.h"

const int controlPin = 13;
int16_t adc0, adc2;
float Vmag1, Vphase1, Vmag2, Vphase2;
float Z, r, du;
float du_rad;
float Rp, Cp;
float Cp_nF;

// VSPI uses default SCLK=18, MISO=19, MOSI=23, SELECT=4 & 5.
SPIClass *myspi = new SPIClass(VSPI);
AD9833 AD(5, myspi);
AD9833 AD2(4, myspi);
Adafruit_ADS1115 ads;
WiFiManager wifiManager;
WiFiConnectionHandler *cloudConnection = nullptr;
Preferences knownNetworks;

constexpr char NETWORKS_NAMESPACE[] = "known-wifi";
constexpr uint8_t MAX_KNOWN_NETWORKS = 5;

String ssidKey(uint8_t index) { return "ssid" + String(index); }
String passKey(uint8_t index) { return "pass" + String(index); }

bool isVisibleNetwork(const String &ssid, int networkCount) {
  for (int i = 0; i < networkCount; ++i) {
    if (WiFi.SSID(i) == ssid) {
      return true;
    }
  }
  return false;
}

bool connectToKnownNetwork() {
  const int networkCount = WiFi.scanNetworks();
  if (networkCount <= 0) {
    Serial.println("No known Wi-Fi networks are visible.");
    return false;
  }

  knownNetworks.begin(NETWORKS_NAMESPACE, true);
  for (uint8_t i = 0; i < MAX_KNOWN_NETWORKS; ++i) {
    String ssid = knownNetworks.getString(ssidKey(i).c_str(), "");
    String pass = knownNetworks.getString(passKey(i).c_str(), "");
    if (ssid.isEmpty() || !isVisibleNetwork(ssid, networkCount)) {
      continue;
    }

    Serial.print("Trying known Wi-Fi: ");
    Serial.println(ssid);
    WiFi.begin(ssid.c_str(), pass.c_str());
    const unsigned long deadline = millis() + 15000;
    while (WiFi.status() != WL_CONNECTED && millis() < deadline) {
      delay(250);
    }
    if (WiFi.status() == WL_CONNECTED) {
      knownNetworks.end();
      return true;
    }
    WiFi.disconnect();
  }
  knownNetworks.end();
  return false;
}

void rememberNetwork(const String &ssid, const String &pass) {
  knownNetworks.begin(NETWORKS_NAMESPACE, false);
  uint8_t targetSlot = MAX_KNOWN_NETWORKS;
  for (uint8_t i = 0; i < MAX_KNOWN_NETWORKS; ++i) {
    String storedSsid = knownNetworks.getString(ssidKey(i).c_str(), "");
    if (storedSsid == ssid) {
      targetSlot = i;
      break;
    }
    if (storedSsid.isEmpty() && targetSlot == MAX_KNOWN_NETWORKS) {
      targetSlot = i;                                          //  slot is empty AND havent found slot yet
    }
  }
  if (targetSlot == MAX_KNOWN_NETWORKS) {                      //  no known Wifi AND no empty slot
    targetSlot = 0;
  }
  knownNetworks.putString(ssidKey(targetSlot).c_str(), ssid);
  knownNetworks.putString(passKey(targetSlot).c_str(), pass);
  knownNetworks.end();
}

bool connectToWifi() {
  WiFi.mode(WIFI_STA);
  // Store our own list of profiles, rather than the single ESP Wi-Fi profile.
  wifiManager.resetSettings();
  wifiManager.setHostname("ESP32-Meter");
  wifiManager.setConnectTimeout(20);
  wifiManager.setConfigPortalTimeout(300);

  if (!connectToKnownNetwork()) {
    Serial.println("Opening Wi-Fi setup portal.");
    if (!wifiManager.startConfigPortal("ESP32-Meter-Setup", "configure-me")) {
      Serial.println("Wi-Fi setup timed out; restarting.");
      ESP.restart();
      return false;
    }

    String ssid = wifiManager.getWiFiSSID(false);
    String pass = wifiManager.getWiFiPass(false);
    rememberNetwork(ssid, pass);
  }

  if (WiFi.status() != WL_CONNECTED) {
    Serial.println("Wi-Fi setup timed out; restarting.");
    ESP.restart();
    return false;
  }

  String ssid = WiFi.SSID();
  knownNetworks.begin(NETWORKS_NAMESPACE, true);
  String pass;
  for (uint8_t i = 0; i < MAX_KNOWN_NETWORKS; ++i) {
    if (knownNetworks.getString(ssidKey(i).c_str(), "") == ssid) {
      pass = knownNetworks.getString(passKey(i).c_str(), "");
      break;
    }
  }
  knownNetworks.end();
  cloudConnection = new WiFiConnectionHandler(ssid.c_str(), pass.c_str());

  Serial.print("Wi-Fi connected: ");
  Serial.println(WiFi.localIP());
  return true;
}

void cloudDelay(unsigned long durationMs) {
  const unsigned long start = millis();
  while (millis() - start < durationMs) {
    ArduinoCloud.update();
    delay(50);
  }
}

void setup() {
  Serial.begin(115200);
  connectToWifi();

  initProperties();
  setDebugMessageLevel(4);
  ArduinoCloud.begin(*cloudConnection, true, "mqtts-up.iot.arduino.cc", 8884);
  ArduinoCloud.printDebugInfo();

  myspi->begin();
  AD.begin();
  AD2.begin();
  AD.reset();
  AD2.reset();

  AD.setFrequency(1000000, 0);
  AD2.setFrequency(1000000, 0);
  AD.setPhase(0);
  AD2.setPhase(90);
  AD.setWave(AD9833_SINE);
  AD2.setWave(AD9833_SINE);
  AD.writeControlRegister(0x2000);
  AD2.writeControlRegister(0x2000);

  Serial.println(AD.getWave());

  ads.setGain(GAIN_TWO);
  if (!ads.begin()) {
    Serial.println("Failed to initialize ADS.");
    while (1) {
    }
  }

  pinMode(controlPin, OUTPUT);
}

void loop() {
  ArduinoCloud.update();

  digitalWrite(controlPin, HIGH);
  cloudDelay(2500);

  adc0 = ads.readADC_SingleEnded(0);
  adc2 = ads.readADC_SingleEnded(2);
  Vmag1 = ads.computeVolts(adc2);
  Vphase1 = ads.computeVolts(adc0);

  digitalWrite(controlPin, LOW);
  cloudDelay(2500);

  adc0 = ads.readADC_SingleEnded(0);
  adc2 = ads.readADC_SingleEnded(2);
  Vmag2 = ads.computeVolts(adc2);
  Vphase2 = ads.computeVolts(adc0);

  r = 47 * pow(10, (Vmag1 - Vmag2) / 0.6);
  du = (Vphase1 - Vphase2) / 0.01;
  du_rad = (du * PI) / 180.0;
  Rp = r / cos(du_rad);
  Cp = - sin(du_rad) / (2 * PI * 1000000 * r);
  Cp_nF = Cp * pow(10, 9);

  rp = Rp;
  cp = Cp_nF;
  ArduinoCloud.update();

  Serial.println("-----------------------------------------------------------");
  Serial.print("Vmag1: "); Serial.print(adc0); Serial.print("  "); Serial.print(Vmag1); Serial.println("V");
  Serial.print("Vphase1: "); Serial.print(adc2); Serial.print("  "); Serial.print(Vphase1); Serial.println("V");
  Serial.print("Vmag2: "); Serial.print(adc0); Serial.print("  "); Serial.print(Vmag2); Serial.println("V");
  Serial.print("Vphase2: "); Serial.print(adc2); Serial.print("  "); Serial.print(Vphase2); Serial.println("V");
  Serial.println("-  -  -  -");
  Serial.print("Rp: "); Serial.print(Rp); Serial.println("Ohms");
  Serial.print("Cp: "); Serial.print(Cp_nF); Serial.println("nF");
  cloudDelay(4000);
}

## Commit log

2026-08-17 Baseline v1: ESP32 Arduino Cloud monitoring
2026-08-17 Add WiFiManager provisioning flow
2026-08-23 Integrate thesis, hardware, and analysis sources
    [SoilBoard.kicad_pcb, SoilBoard.kicad_sch]
2026-08-23 Organize firmware, PCB, and impedance analysis
    [SoilBoard.kicad_pcb, SoilBoard.kicad_sch]
